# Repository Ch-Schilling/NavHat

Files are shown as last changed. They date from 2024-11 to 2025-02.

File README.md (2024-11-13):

# NavHat
NavHat or Navigaion Hat is a Raspberry Pi HAT made for saling boats. The HAT implements a number of features to make the Raspberry Pi suitable for a sailing boat environment. It provides power to the Raspberry Pi from board supply, collects data from NMEA bus and attached sensors. It provides the hardware base for an Open Source Navigation platform.
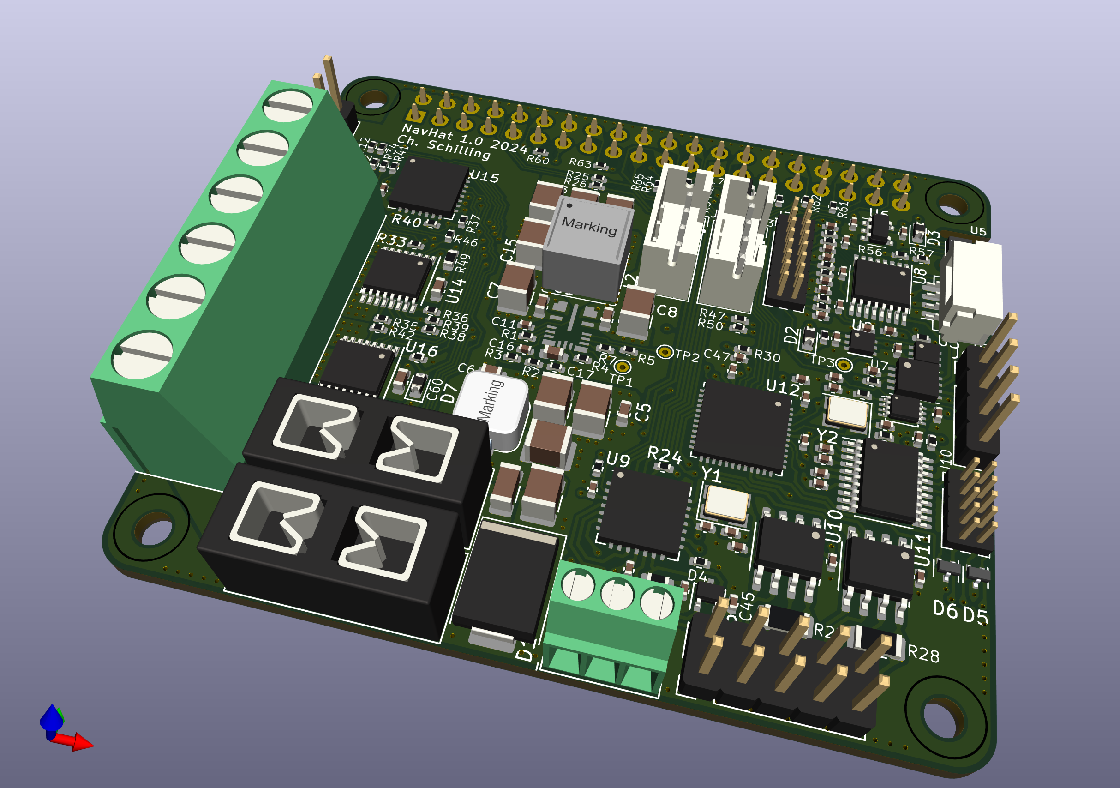
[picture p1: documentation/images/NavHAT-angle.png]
Rendered NavHAT board


**Features:**
* Powered by board supply of 12-28V DC
* Onboard fuses for Raspberry and power outputs
* Four Power Outputs of up to 6A with current and temperature monitoring
* Very low sleep current
* Wake-up by key or RTC
* barometric sensor
* CAN interface for NMEA2000 network
* RS232 and RS422 interfaces for NMEA0183 devices
* Sensor interfaces with STEMMA and Qwiic compatibility
* Designed for compatibility to Raspberry Pi HAT specification

The board is designed using KiCad. 
For more details, see the corresponding [documentation](./documentation/NavHAT.md).

I hope you like the project as much as I do. In case of interest of the board itself, please contact me.

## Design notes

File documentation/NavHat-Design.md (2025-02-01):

## Design
The design is made using KiCad. It is impressive how well that open source system is capable of drawing schematics and designing PCBs! Cudos to the KiCad team. Get the design files from the KiCad folder.
The board is designed for four copper layers to achieve the densitiy needed for the small footprint of the HAT as well as thermal and EMI reasons. For easyer manufacturing, components are populated on the top side only. KiCad and open hardware logos are printed on the bottom side of the board.

### Power Supply
To operate a Raspberry Pi with Navigation HAT independent of other installation, two fuses are on board. F1 (approx. 3A) is installed in the path of the power supply for the Raspberry Pi, F2 (approx. 20A) is in place for the four power outlets.
The fuses are specified for 32V DC, therefore the supply voltage shall not exceed this value.
To achieve high efficiency, low noise, low stand-by current and a wide voltage input the TI LM62460 was chosen. The part also offers a wide range switching frequency and a spread spectrum option. To optimize efficiency, the switching frequency is set to 488kHz. Higher frequencies would allow to use smaller inductors. An EMI filter is used at the battery side. Electrolythic capacitors are waived, purely ceramic capacitors are used. See schematics page 2 and the [datasheet](https://www.ti.com/product/de-de/LM62460) of the manufacturer.
The Enable signal EN_POWER of the device is controlled by a flip-flop U4. EN_POWER is high and remains high if POWER_ON gets low by an external signal like a button, power-on cycle or an interrupt of the RTC. The flip-flop consumes very little power, it has to remain on by a low Iq linear regulator U2. In case of shutting down the Raspberry Pi, the gpio-poweroff driver is used to rise the clock signal of the flip-flop, disabling the DC/DC converter and put it into µA current consumption sleep mode. To do so, this needs to be added in the /boot/firmware/config.txt file:
```
dtoverlay=gpio-poweroff,gpiopin=5,active-delay-ms=1000
```
The active-delay is not mandatory, but seems to be a good idea.
> Note: Make sure that there are no pending interrups of the RTC, otherwise the flip-flop cannot change state and turn off the DC/DC converter.

### Power Outlets
To control lights, relays or board instruments 4 power outlets are available. The high side switche family [TPS2HB](https://www.ti.com/product/TPS2HB16-Q1) of TI is used. The parts provide low R_on resistance, current limiter and -monitoring as well as temperature monitoring. Made for the automotive market, they seem to be a good fit for boating applications, too. The parts are controlled via a I2C port extension device MCP23017. To save the part from reverse polarity 15kOhm resistors are used in all digital paths as described in the application notes.
A fraction of the output current can be fed throug a sense resistor to measure the output current. The voltage across the shunt resistor can be measured by the on-board ADC. Optionally, the first two switches can be controlled by the PWM engine of the Raspberry Pi. Please be aware that not all features of that mini computer can be used at the same time.
> Warning: Do not drive PWM and the corresponding pin of the IO expander at the same time. One of these signals shall remain as an input.

### NMEA Interfaces
The NMEA 2000, CAN interface is implemented using a Microchip MCP25625. The MCP25625 is a more modern and compact device containing a MCP2515 and corresponding bus driver. It creates a one chip solution from SPI to CAN bridge. From the Raspberry Pi's perspecive the MCP2515 driver is used. Make sure the /boot/firmware/config.txt contains the following:
```
dtparam=spi=on
dtoverlay=mcp2515-can0,oscillator=20000000,interrupt=25,spimaxfrequency=2000000
```
In a console, configure the CAN bus for NMEA 2000:
```
sudo ip link set can0 up type can bitrate 250000
sudo ip link set can0 txqueuelen 65536
```
Check for can0 interface using
```
ip link
```
candump displays the traffic in a console. NMEA 2000 bus data should be easily visible but not readable. 
```
candump can0
```

For more details pyssel describes to setup NMEA 2000 with a CAN HAT on their [webpage](https://pysselilivet.blogspot.com/2022/05/waveshare-can-hat-with-signal-k.html)

For NMEA 0183 devices and/or other serial devices, a MAX14830 bridges SPI to quad UART. The first two UARTs are converted into RS-422 signals and fed to connector J9. The last two UARTs can be converted to RS-232 signals and fed to connector J10. One can use the TTL signals but one has to disable the converter chip U13 and put it into shutdown mode. The quad UART U12 could have its own quatz, since it has a wide possibility of options to create its clocks, the clockout of the CAN chip U9 shall be used instead.
The CAN and RS-422 interfaces have an option of a termination resistor of typically 120Ohm, but these resistors are not populated by default. ESD protection diodes are used except for the RS-422 devices, they have large enough built-in protection.

### Sensors and Sensor Interfaces
There are a wide variety of sensors with I2C interface. On board, the following parts share the user accessible I2C bus of the Raspberry Pi:
* MCP23017 I/O Port extension for controlling the power outlets
* ADS1119 analog to digital converter for measuring current and temperature of the power outlets
* MAX31343 RTC for wake up calls
* BMP390 barometric pressure sensor

The BMP390 is susceptible to stress. It is placed at the edge of the board in between two cutouts. Stress to the board is not passed to the part where the sensor is soldered to.
  
There are two [STEMMA](https://learn.adafruit.com/introducing-adafruit-stemma-qt/what-is-stemma) connectors J3 and J4 as well as a STEMMA QT / Qwiic connector J5. The power pin of J5 is hooked up from linear regulator U2. It provides 3.3V even if the main DC/DC converter is switched off. This allows low power sensors to continue to operate without operation of the computer. The header J7 also carries the two I2C signals. There should be plenty of options to add I2C sensors to the system.
Connector J2 is prepared for 1-wire devices inclusive 5kOhm pull-up and 3.3V and 5V to chose from.

A nice option for environmental monitoring of temperature and humidity, the part HDC3020 can be used. It is not on board because the environment of the computer system is typically not representative for the environment to be monitored. The part continues to measure these parameters, even if there is no I2C communication. It stores the minimum and maximum measurements of temperature and rel. humidity. This is an excellent choise to connect to J5 to be powered, even when the Raspberry Pi is off. The computer can read the min. and max. readings when it is awake again.

### Configuration
#### EEPROM
Page 6 of the schematics shows hardware configurations of the board. The HAT specification requires a EEPROM describing the HAT and holds information about power delivery and required drivers. Unlike the proposal of the HAT specification, a software configurable EEPROM is used. This allows to set the I2C address as well as the write protection of the device within a minimal board space. Gaining write access to the device from user space is relatively complicated, therefore an accidential write access is highly unlikely.

Writing to the configuration EEPROM is easy using the software gpio driver. A new bus is createt, for example 9. Use this driver only temporary before accessing the configuration memory to prevent unwanted modification.
```sh
sudo dtoverlay i2c-gpio i2c_gpio_sda=0 i2c_gpio_scl=1 bus=9
```
Check if somebody is home. The memory chips are expected in the address range 0x50 ... 0x57.
```sh
i2cdetect -y 9

     0  1  2  3  4  5  6  7  8  9  a  b  c  d  e  f
00:                         -- -- -- -- -- -- -- -- 
10: -- -- -- -- -- -- -- -- -- -- -- -- -- -- -- -- 
20: -- -- -- -- -- -- -- -- -- -- -- -- -- -- -- -- 
30: -- -- -- -- -- -- -- -- -- -- -- -- -- -- -- -- 
40: -- -- -- -- -- -- -- -- -- -- -- -- -- -- -- -- 
50: 50 -- -- -- -- -- -- -- -- -- -- -- -- -- -- -- 
60: -- -- -- -- -- -- -- -- -- -- -- -- -- -- -- -- 
70: -- -- -- -- -- -- -- --
```

check configuraton directory for files and scripts. The eep tools are used to create binary files from a text description and writing the image into the configuration memory. See HAT documentation for more details. A device tree blob can be added to the binary description which is executed at boot time. The power-5A.dtbo promisses to provide 5A current. The Raspberry Pi 5 is complaining about a weak power supply if that is not provided.
```sh
eepmake  -v1 eeprom_navhat.txt eeprom_navhat.eep power-5A.dtbo
```
The shell script eepflash.sh finally writes the image into the memory device.
```sh
sudo eepflash.sh -w -f eeprom_navhat.eep -d=9 -t=24c64
```
To set the I2C Address of the device or write protecting the memory content, eeprom_config.py can be used. 
```sh
python3 eeprom_config.py -b 9 -a 0x52 --write-protect
```
changes the address to 0x52 and sets the write protection.
The device tree blob is created from its source file like that:
```sh
dtc -@ -O dtb -I dts -o power-5A.dtbo power-5A.dts
```
The build.sh script executes these commands in the correct order.

#### SPI 
Chip select and interrup pin for the CAN- and UART controller are prepared for two options. The options can be chosen by using the corresponding resistor.

#### I2C
The signal I2C_ADDR0 can be set to logic 0 or logic 1. It is connected to the lowest address bit of the pressure sensor U5, the ADC U8 and the port extender U15. The I2C address of these devices can be rised by 1 commonly in case of conflict with other devices.

The following table shows the I2C addresses of the different devices. A0 corresponds to the configuration of the I2C_ADDR0 which can be set by the resistors R56 and R57. A0 = 0 if R57 is populated and A0 = 1 if R56 is populated, respectively.

|Device|Address|
|:-----|:---|
|MCP23017|0x22 + A0|
|BMP390|0x76 + A0|
|ADS1119|0x48 + A0|
|MAX31343|0x68|
|HDC3020|0x44|

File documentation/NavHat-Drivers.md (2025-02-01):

## Drivers

To make full advantage of the board, two drivers need attention: the CAN device MCP25625 and the quad UART MAX14830. These communication devices share one oscillator. The CAN chip needs to be configured to provide a clock output which is used as a clock input for the quad UART device. The quad UART driver is not included in the kernel by default, it must be added as max310x module. 
The clock output did not find attention by the kernel maintainers, so far. A patch is added that allows a user friendly configuration of the clock output signal.

To compile the kernel follow these well [documented steps of the raspberry pi documentation.](https://www.raspberrypi.com/documentation/computers/linux_kernel.html#configure-the-kernel)

To enable the quad UART max14830, make sure the .config shows this driver as a module:
```
CONFIG_SERIAL_MAX310X=m
```
Add the patch for the mcp250x driver and corresponding device tree files or swap the entire kernel source files.
Compile the kernel afterwards.

### CAN driver
To configure the output clock CLKOUT, a field was introduced in the mcp2515-can0-overlay.dts device tree overlay file.
```
          clkout-prescale = <0>;
```

The driver looks for that entry during probing and sets the CANCTRL register accordlingly. A value of 0 does not enable clock output and remains the output low. In this case, the driver behaves no different than the original version does.
Valid parameters for clkout-prescale are 1,2,4 and 8 which divides the input clock by 1 (same frequency), 2 ,4 or 8 respectively.

This information can be found by the driver using device_property interface during probing:
```
	/* check clkout property and convert it to register value */
	if(device_property_present(&spi->dev, "clkout-prescale")) {
		dev_info(&spi->dev, "clkout-prescale: found\n");
		device_property_read_u32(&spi->dev, "clkout-prescale", &clkout_prescale);
		dev_info(&spi->dev, "clkout-prescale found: %d\n", clkout_prescale);
		if(clkout_prescale) {
			if (clkout_prescale > 8)
				return -ERANGE;

			clkout_prescale = (clkout_prescale >> 1);
			clkout_prescale = (clkout_prescale == 4 ? 3 : clkout_prescale) | CANCTRL_CLKEN;
			dev_info(&spi->dev, "(CS) clkout-prescale register value: 0x%02x.", clkout_prescale);
		}
	}
	...
```
This is for illustration only, no actions needed for commissioning.

### UART driver
The driver for the MAX14830 works without modification but a device tree overlay is needed to hook it correctly in the SPI 1 bus. The following line creates a device-tree blop which needs to be copied to /boot/firmware/overlays using root priviledges.
```
dtc -@  -O dtb -I dts -o max14830-spi1.dtbo max14830-spi1-overlay.dts 
```

Describing the clock input is 2.5MHz, 1/8 of the 20MHz oscillator for the CAN device. The UART uses a PLL and internal prescaler to adjust the baudrate as close as pssible to the desired one. Below are exceprts from max14830-spi1-overlay.dts.
```
	fragment@3 {
		target-path = "/clocks";

		__overlay__ {
			max14830_xtal: max14830_xtal {
				compatible = "fixed-clock";
				#clock-cells = <0>;
				clock-frequency = <2500000>;
			};
		};

	};
```
Also, clock-names has to be "osc" for an external input. "xtal" is used for a quarz.
```
	fragment@1 {
		target = <&spi1>;

		__overlay__ {
			#address-cells = <1>;
			#size-cells = <0>;

			pinctrl-names = "default";
			pinctrl-0 = <&spi1_pins &spi1_cs_pins>;

			cs-gpios = <&gpio 17 1>;  //GPIO_ACTIVE_LOW>;
			status = "okay";

			max14830: max14830@0 {
				compatible = "maxim,max14830";
				reg = <0>;

				#address-cells = <1>;
				#size-cells = <0>;
				gpio-controller;
				#gpio-cells = <2>;

				spi-max-frequency = <5000000>;
				interrupts = <12 8>; // 2:IRQ_TYPE_EDGE_FALLING>;  8:low
				interrupt-parent = <&gpio>;

				pinctrl-0 = <&int_pins>;
				pinctrl-names = "default";

				clocks = <&max14830_xtal>;
				clock-names = "osc";
			};
		};
	};

```
It seemed that some interupts got lost when the interrupt signal was configured as falling edge. Setting it to low (8) seems to solve that problem.

To load these drivers at boot time, make sure they are mentioned in the /boot/firmware/config.txt file:
```
...
dtparam=spi=on
dtoverlay=mcp2515-can0,oscillator=20000000,interrupt=25,spimaxfrequency=2000000,clkoutprescale=8
dtoverlay=max14830-spi1
...
```

If configured correctly the two drivers appear in dmsg after reboot.
```
...
[   11.391625] mcp251x spi0.0: clkout-prescale: 4
[   11.417303] mcp251x spi0.0 can0: MCP2515 successfully initialized.
...
[   11.471622] spi1.0: ttyMAX0 at I/O 0x0 (irq = 172, base_baud = 3750000) is a MAX14830
[   11.479118] spi1.0: ttyMAX1 at I/O 0x1 (irq = 172, base_baud = 3750000) is a MAX14830
[   11.483086] spi1.0: ttyMAX2 at I/O 0x2 (irq = 172, base_baud = 3750000) is a MAX14830
[   11.483433] spi1.0: ttyMAX3 at I/O 0x3 (irq = 172, base_baud = 3750000) is a MAX14830
...
```

The CAN driver mcp251x displays the clkout-prescale if found and its successful initialization. The single nodes of the UART can be accessed using /dev/ttyMAX0 ... /dev/ttyMAX3. Make sure to turn off hardware handshaking, because these lines are not wired. The upper two (ttyMAX2 and ttyMAX3) can be configured to use the RS-232 level shifter or to keep the TTL signals. Enable and shutdown of the the level shifter are controlled by GPIO0 and GPIO1 of the UART. Since the UART device acts as a standard gpio controller these lines can be set as follows:
```
gpioset --drive=push-pull gpiochip14 0=1 1=0
```
Sets GPIO0 to high and GPIO1 to low, which disables the level shifter.

```
gpioset --drive=push-pull gpiochip14 0=0 1=1
```
Sets GPIO0 to high and GPIO1 to low, which enables the level shifter.

Depending on the configuration, gpiochip14 might not be the correct device. Try to use gpiodetect to find the correct one.
```
user@raspberrypi:~ $ gpiodetect
gpiochip0 [pinctrl-rp1] (54 lines)
gpiochip10 [gpio-brcmstb@107d508500] (32 lines)
gpiochip11 [gpio-brcmstb@107d508520] (4 lines)
gpiochip12 [gpio-brcmstb@107d517c00] (17 lines)
gpiochip13 [gpio-brcmstb@107d517c20] (6 lines)
gpiochip14 [MAX14830] (16 lines)
gpiochip0 [pinctrl-rp1] (54 lines)
```
gpioinfo shows the status of all GPIO signals of the system:
```
...
gpiochip14 - 16 lines:
        line   0:      unnamed       unused  output  active-high 
        line   1:      unnamed       unused  output  active-high 
        line   2:      unnamed       unused   input  active-high 
        line   3:      unnamed       unused   input  active-high 
...
```

To see how much data was transferred by the four UARTs as well as the line stati, check the driver information:
```
user@raspberrypi:~ $ sudo cat /proc/tty/driver/max310x
serinfo:1.0 driver revision:
0: uart:MAX14830 port:00000000 irq:172 tx:0 rx:0 DSR|CD
1: uart:MAX14830 port:00000001 irq:172 tx:0 rx:0 DSR|CD
2: uart:MAX14830 port:00000002 irq:172 tx:0 rx:0 DSR|CD
3: uart:MAX14830 port:00000003 irq:172 tx:0 rx:0 DSR|CD
```

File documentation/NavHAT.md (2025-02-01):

# Navigation HAT
The Navigation HAT is a board that connects on top of the Raspberry Pi computer by its 40 pin header. HAT stands for Hardware-Attached-on-Top, the specification can be found [here](https://datasheets.raspberrypi.com/hat/hat-plus-specification.pdf).

Rendered NavHAT board

## Purpose
Navigation HAT is made to help embed the Raspberry Pi in a sailing boat. Of course, it can be used in many other use cases where the hardware features make sense.
On a sailing boat, one is consious about power consumption. Navigation HAT uses a wide input range, high efficiency and low noise step-down switcher providing power to the Raspberry Pi. In operation, powered from the battery of the boat, its efficiency is approx. 95%.
In standby, it uses only a few µA. It can be woken up by a key or by the on-board real time clock (RTC).
Most boats use NMEA 2000 for information exchange between instruments, plotter, autopilot etc. The bus is based on CAN, therefore an important interface is the CAN bus. Older boats might use NMEA 0183, which is based on RS-422. Two UARTs each in RS-422 and RS-232 configuration are populated as well.
To control other loads on the boat, there are four power outputs with current limitation and monitoring as well as other protective features. Barometric readings are essential for wheather observation. A high sensitivity barometric sensor is included. Several connectors are ready for attaching other sensors using a two-wire bus.

## [Installation](./NavHat-Installation.md)

## [Design](./NavHat-Design.md)

## [Drivers](./NavHat-Drivers.md)

## Revision history
### Board Revision 1.0
This board revision is first built in April 2024. It is basically functioning. See CoC of the manufacturer in the documentation folder.

### Known issues
* ~~The quad UART is not commissioned, yet.~~
* ~~One-wire is not commissioned, yet.~~
* The quartz Y1 for the CAN device is a 20MHz version. Schematics needs to be fixed (shows 16MHz version)
* The Raspberry Pi 5 leaves its power-off pin in an undefinded state, too long. The signal oscillates and therefore power-off is not reliable. Use a 1KOhm resistor instead of a 100kOhm for R10. Raspberry Pi 4 is fine with the 100kOhm.
* The pull-up and -down resistors of the RS-232 level shifter for /EN and /Shutdown should be the other way around. A TTL serial link could compete with the outputs of the level shifter before setting them correctly.

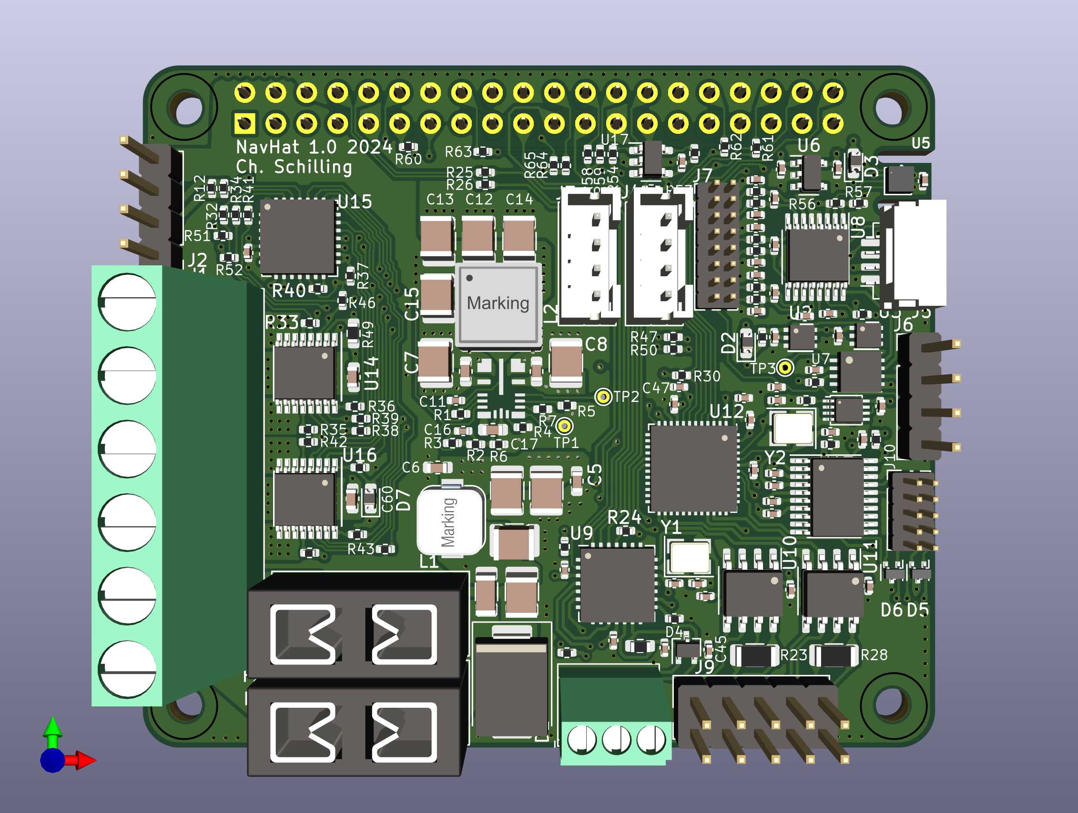
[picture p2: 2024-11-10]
documentation/images/NavHAT-Top.png

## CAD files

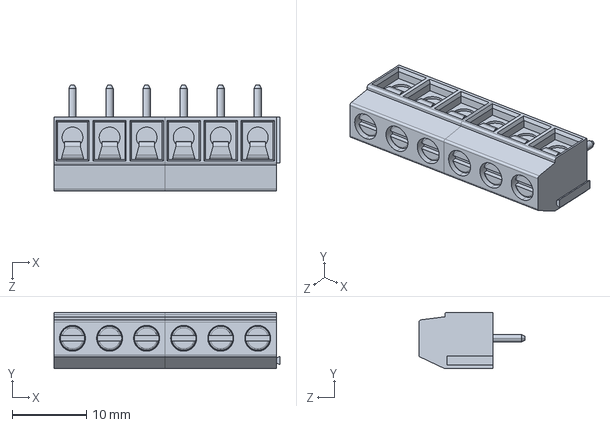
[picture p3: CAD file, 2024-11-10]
KiCad/3D-Step/CUI_DEVICES_TB002-500-06BE.step
30.5 x 7.60 x 14.4 mm
TB002-500-03P_Blue - S x 2

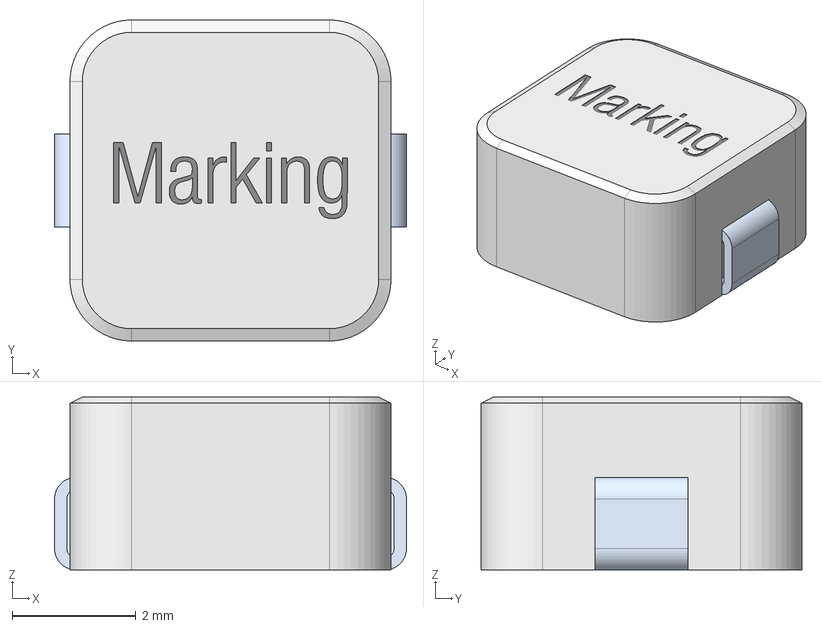
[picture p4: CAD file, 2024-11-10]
KiCad/3D-Step/WE-LHMI_5030.stp
5.70 x 5.20 x 2.80 mm
base
pin

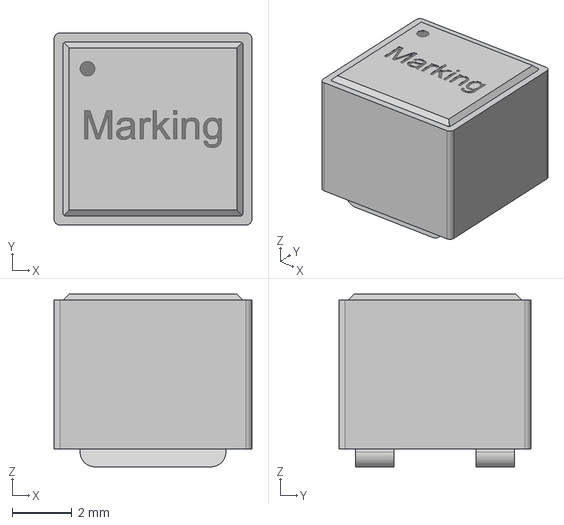
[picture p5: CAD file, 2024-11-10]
KiCad/3D-Step/WE-XHMI-6060.stp
6.65 x 6.45 x 5.80 mm

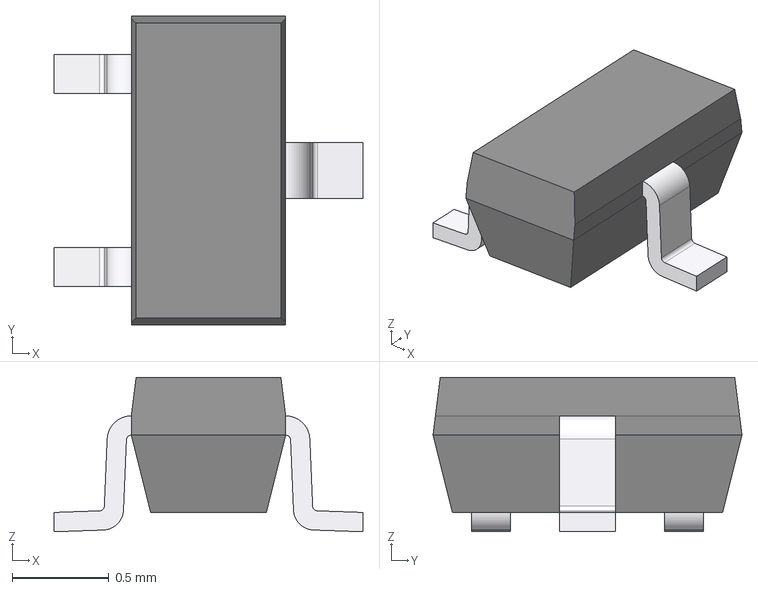
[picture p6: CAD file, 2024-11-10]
KiCad/3D-Step/SOT-523.step
1.60 x 1.60 x 0.8 mm

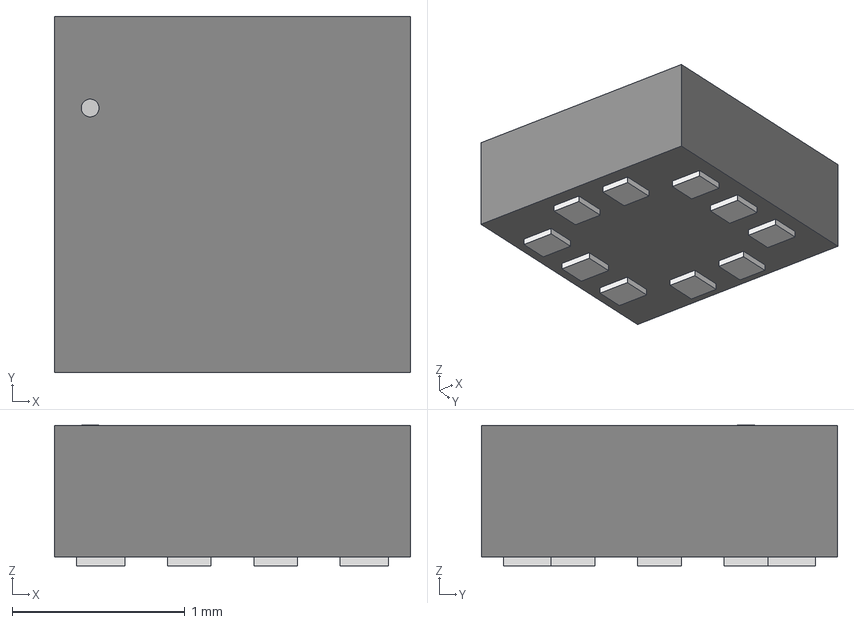
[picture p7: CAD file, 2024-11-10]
KiCad/3D-Step/QFN_BMP388_BOS.step
2.06 x 2.06 x 0.815 mm

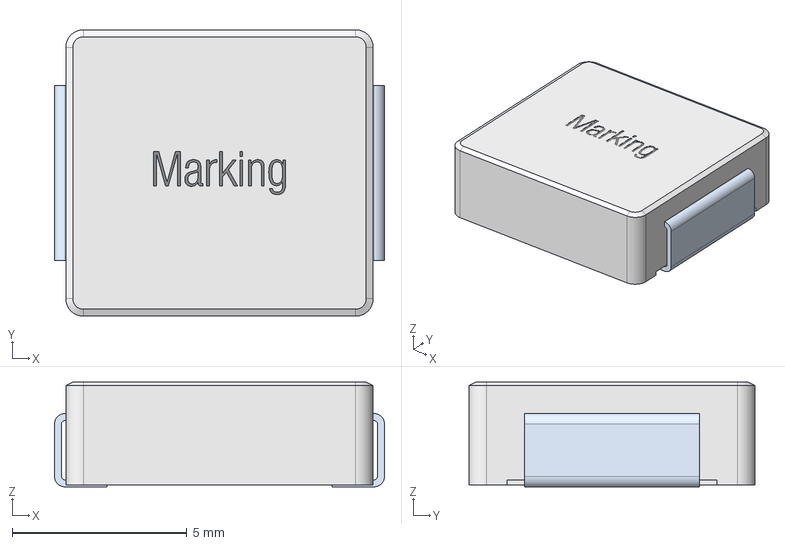
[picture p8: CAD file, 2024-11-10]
KiCad/3D-Step/WE-LHMI-8030.stp
9.45 x 8.20 x 3.00 mm
base
pin

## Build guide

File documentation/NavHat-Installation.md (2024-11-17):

# Installation and Interface Description
Before powering the system, make sure the two fuses are installed. F1 is at the board edge and protects the power path to the Raspberry Pi. Populate with 3A typically. For example, use Littlefuse 0297003.wxnv. F2 is in the path to the power outlets. Let's assume to limit the sum of the current outlets to 20A. Therefore, one can use the Littlefuse 0297020.wxnv, as an example.

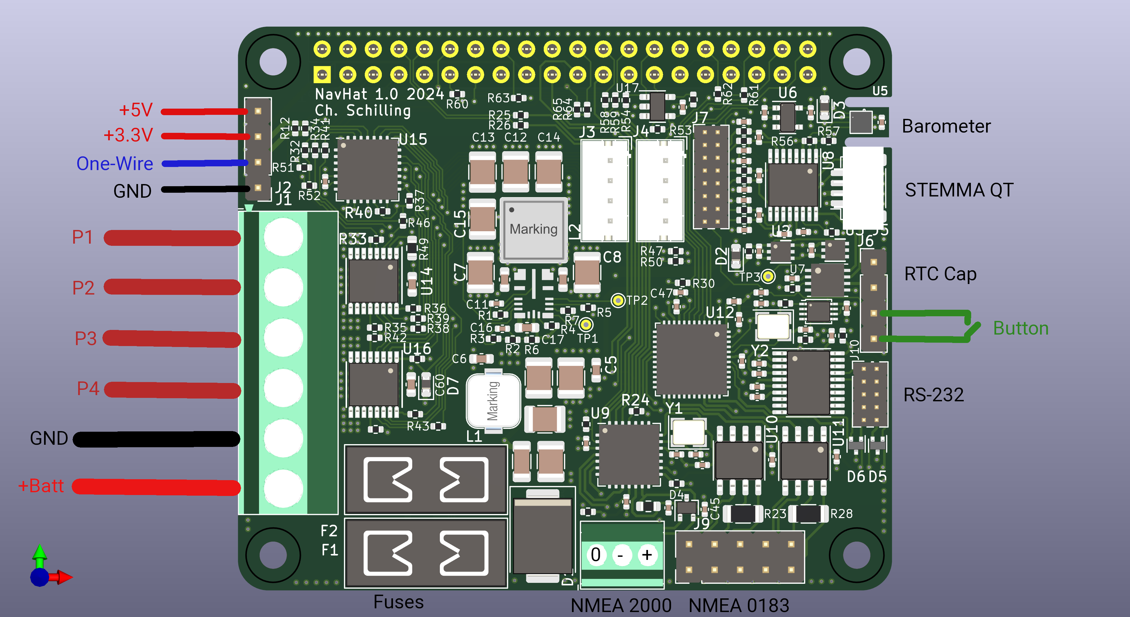
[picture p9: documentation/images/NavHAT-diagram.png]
Diagram and Connections


### Powering the system
J1 is the large screw terminal providing power to the system and connecting loads conrolled by the high-side switches. Positive voltage from the battery is connected closest to the fuses.

|Pin|Connection|
|:--|:---|
|1|P1 Output|
|2|P2 Output|
|3|P3 Output|
|4|P4 Output|
|5|GND, Battery -|
|6|Supply, Battery +|

The screw terminals take wire sizes up to 2.5mm<sup>2</sup>.
> Warning! 
> Use either the USB Power of the Raspberry Pi or the supply for the Navigation HAT board. Do not use both at the same time!

### NMEA 2000 interface
J8 is the small screw terminal for the NMEA 2000 or CAN bus interface. Pin 1 is closest to the fuses.

|Pin|Connection|Color|
|:--|:----|:---|
|1  |GND  |metallic|
|2  |CAN -|blue |
|3  |CAN +|white |

The colors refer to the NMEA cable specification. Use the metallic shield for ground connection.

### Power-on and RTC backup
J6 is reserved for RTC battery or super capacitor as well as the power-on button to switch the flip-flop and therefore start the DC/DC switcher.

|Pin|Connection|
|:--|:---|
|1|GND |
|2|VBATT_RTC |
|3|POWER_ON  |
|4|GND |

Connect POWER_ON to GND for an instant to turn on the system. This is a good application for a power button. 
> Note: It is planned to use the button during operation as a signal and long-press to initiate shut-down. This is not implemented, yet.

### One-Wire
J2 offers a One-Wire interface. The Bit-banging driver of the Raspberry Pi is used. There is a 5kOhm pull-up resistor on board for a seamless start.

|Pin|Connection|
|:--|:---|
|1|GND |
|2|One-Wire |
|3|+3.3V |
|4|+5V |

The +5V is directly connected to the output of the DC/DC converter. +3.3V is made by the Raspberry Pi and is taken from the 40Pin header. Pin 1 is at the Label J2 or closest to J1.

### Auxilary header J7
J7 offers differential signals to the ADC inclusive external differential reference voltage. Four GPIOs from the Port extender, I2C and a linear 3.3V supply are fed to that header as well.

|Signal |Pin|Pin|Signal |
|:---|:-:|:-:|:---|
| GND | 1 | 2 | LIN3V3 |
| SCL | 3 | 4 | SDA |
| GPIO_A4  | 5 | 6 | AIN3 |
| GPIO_A3  | 7 | 8 | AIN2 |
| GPIO_A2  | 9 | 10| REF_N |
| GPIO_A1  | 11| 12| REF_P |
| GND | 13| 14| CurSenseRef |
| POWER_ON | 15| 16| CurSense |

The current sense signals are hooked up to that header, too. Removing R47 and R50 looses current sense of the power outputs in favour of additional external analogue voltages. See schematics for applied filters to the ADC.

### STEMMA connectors J3 and J4
Two STEMMA connectors for external I2C devices are available. For reference, these signals are hooked up like the table below:

|Pin|Signal|
|:--|:-----|
|1 |SCL |
|2 |SDA |
|3 |LIN3V3 |
|4 |GND |

Pin 3, LIN3V3 is powered from a linear regulator, not from the 3.3V of the Raspberry Pi.

### STEMMA QT / Qwiic connector J5

The miniature version of STEMMA can be used on J5. For reference, these signals are hooked up like the table below:

|Pin|Signal|
|:--|:-----|
|1 |GND |
|2 |+3.3VA |
|3 |SDA |
|4 |SCL |

> Note: +3.3VA is powered from a linear regulator and is active, even when the DC/DC converter is disabled.

### NMEA 0183 / serial connectors
J9 and J10 are connectors for RS-232 and RS-422. Details will be updated later.

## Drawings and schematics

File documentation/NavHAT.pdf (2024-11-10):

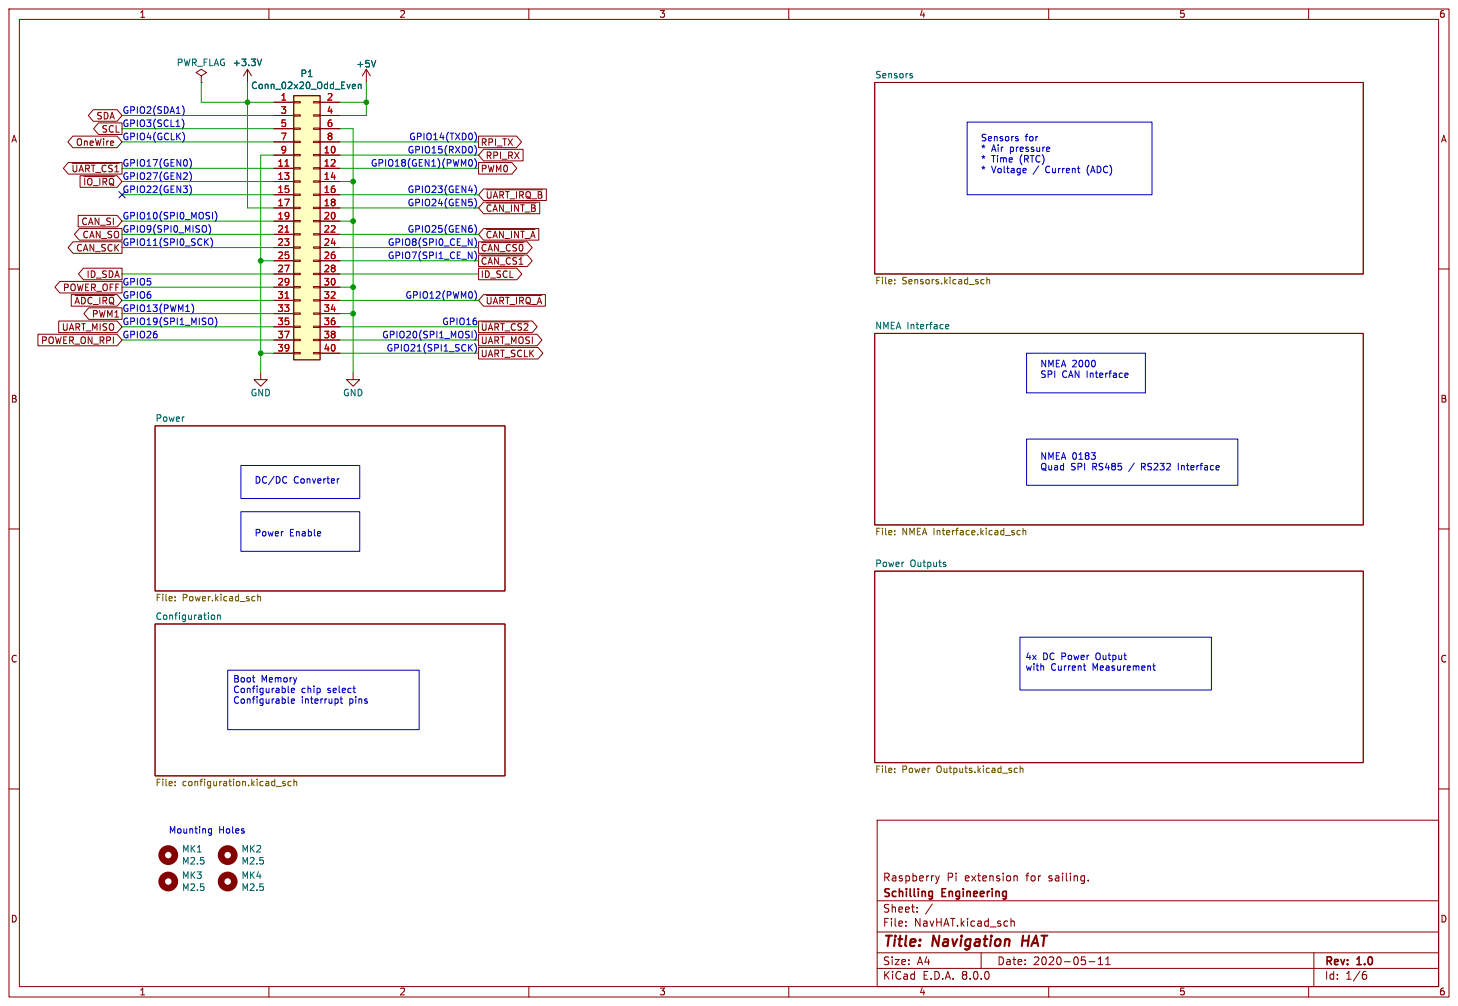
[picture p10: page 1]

Sensors File: Sensors.kicad_sch NMEA Interface File: NMEA Interface.kicad_sch

* Time (RTC) * Voltage / Current (ADC) 4x DC Power Output with Current Measurement Boot Memory

Id: 1/6 Title: Navigation HAT

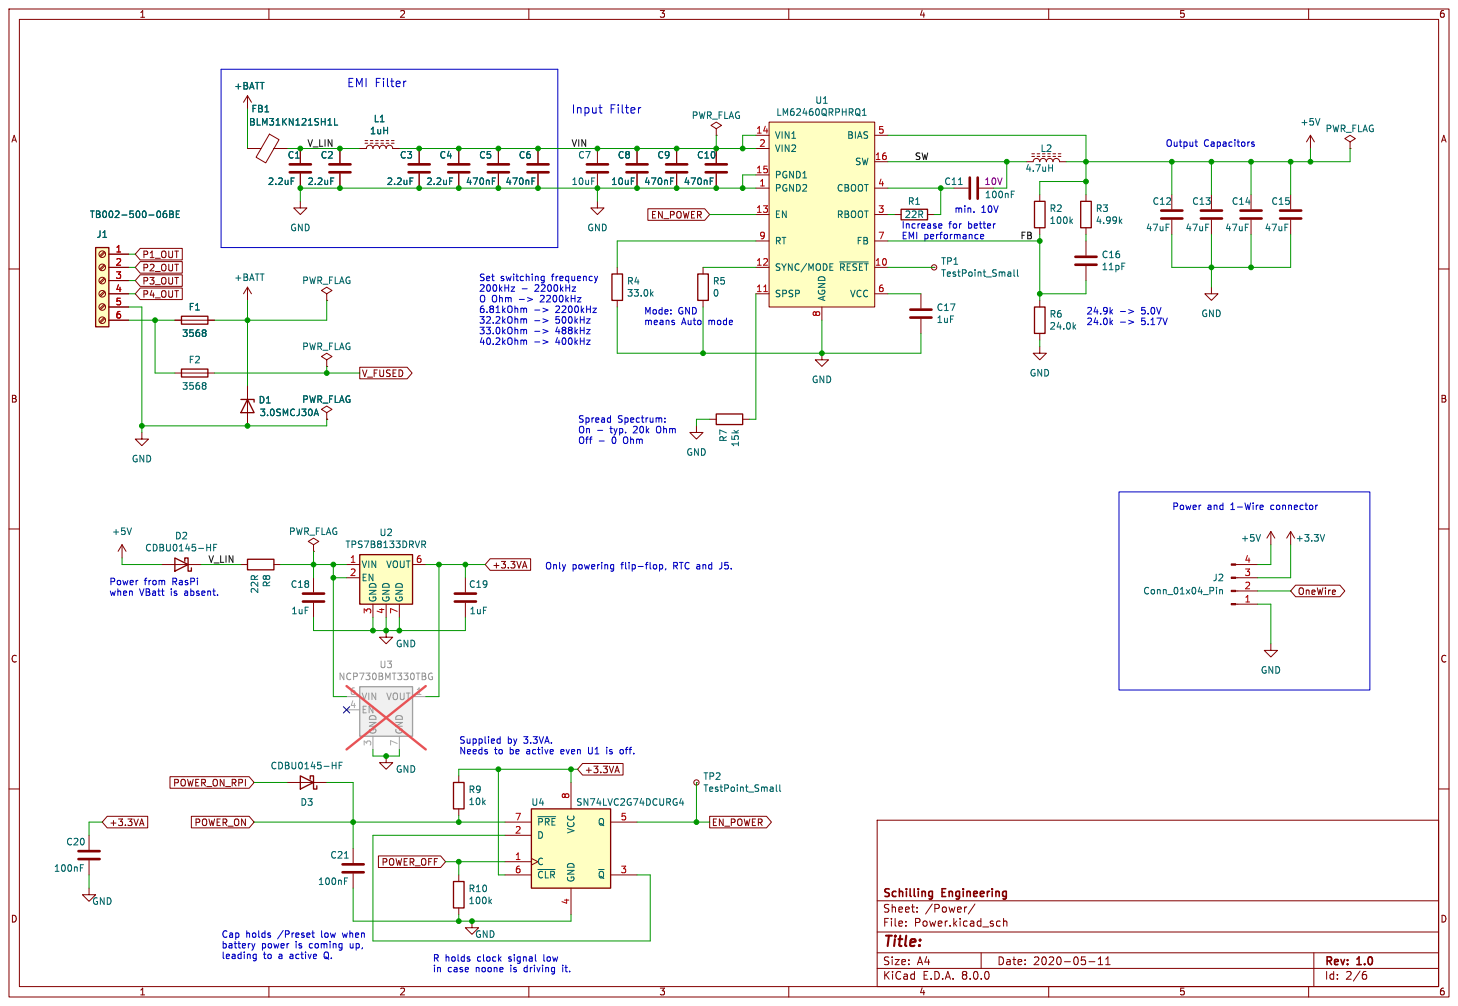
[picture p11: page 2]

EMI Filter
Supplied by 3.3VA. Needs to be active even U1 is off. Mode: GND means Auto mode C9

Increase for better EMI performance

Spread Spectrum: On - typ. 20k Ohm

battery power is coming up,
leading to a active Q.

in case noone is driving it.

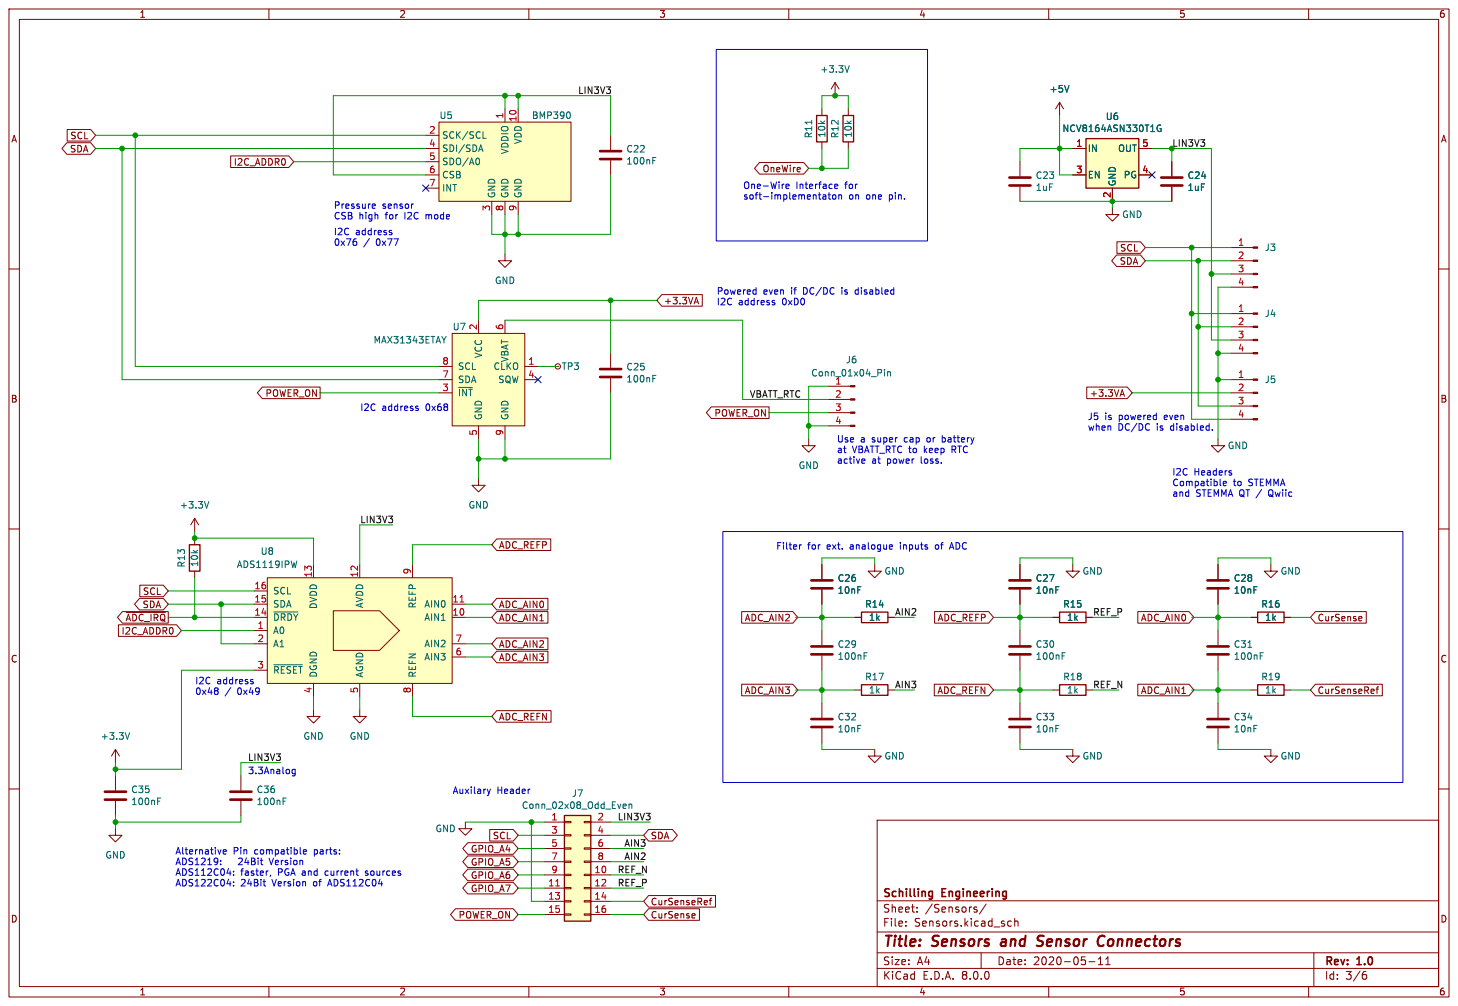
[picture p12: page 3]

1 VDD 10 SCK/SCL 2 GND

3 SDI/SDA 4 SDO/A0 5 CSB 6

and STEMMA QT / Qwiic Pressure sensor CSB high for I2C mode

Powered even if DC/DC is disabled

J5 is powered even when DC/DC is disabled.

active at power loss. 3.3Analog

Id: 3/6 Title: Sensors and Sensor Connectors

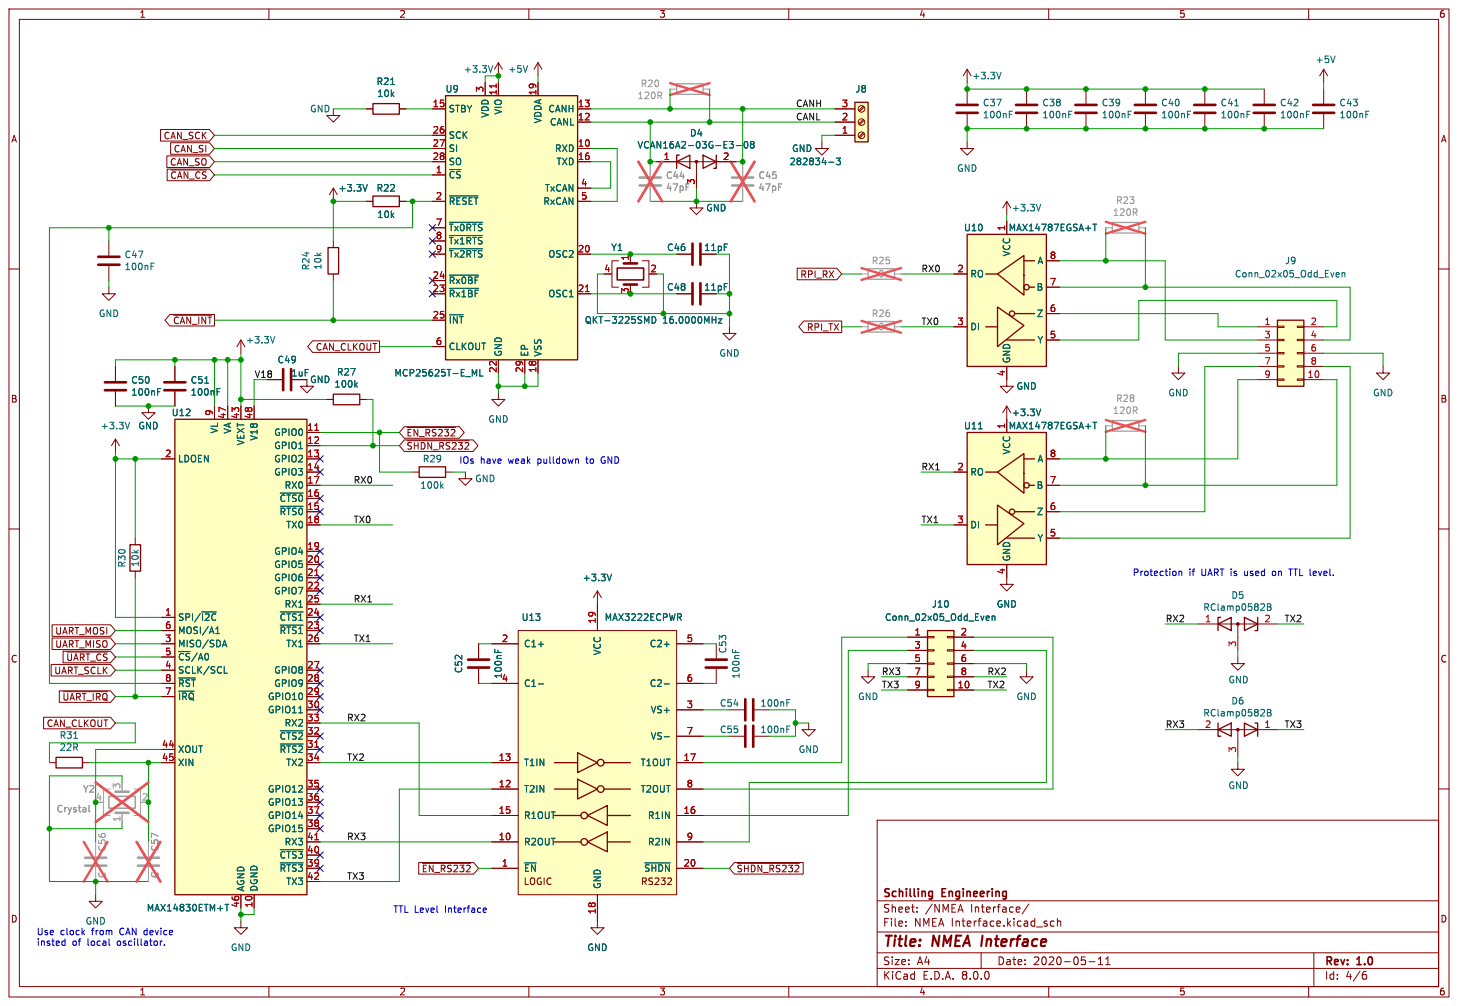
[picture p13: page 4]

Id: 4/6 Title: NMEA Interface

insted of local oscillator.

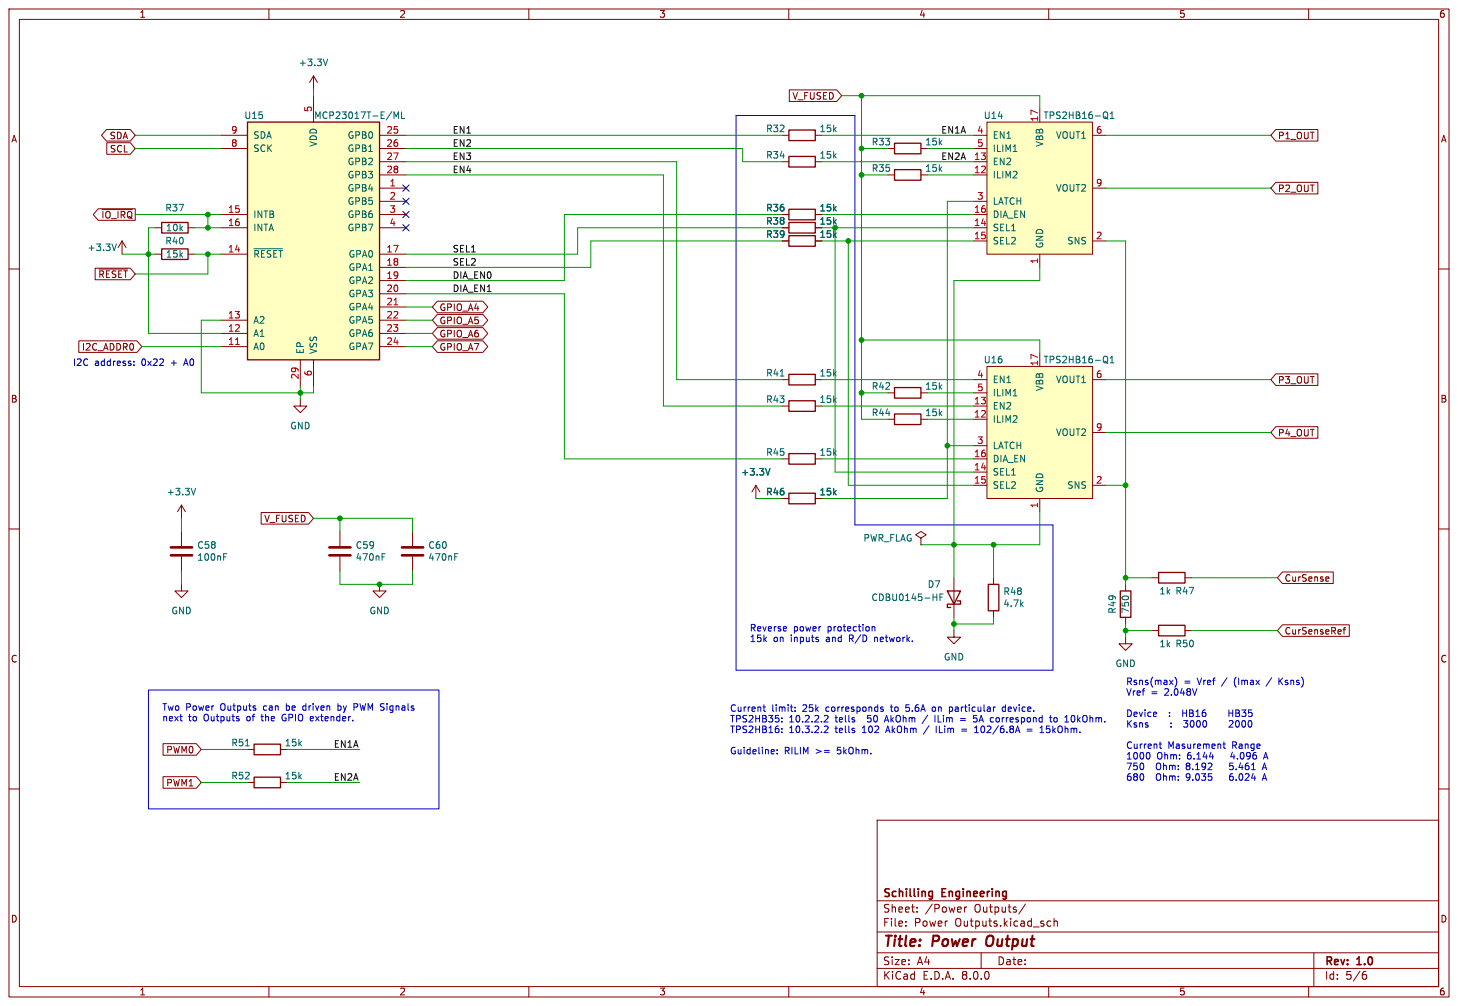
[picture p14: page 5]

Two Power Outputs can be driven by PWM Signals next to Outputs of the GPIO extender.

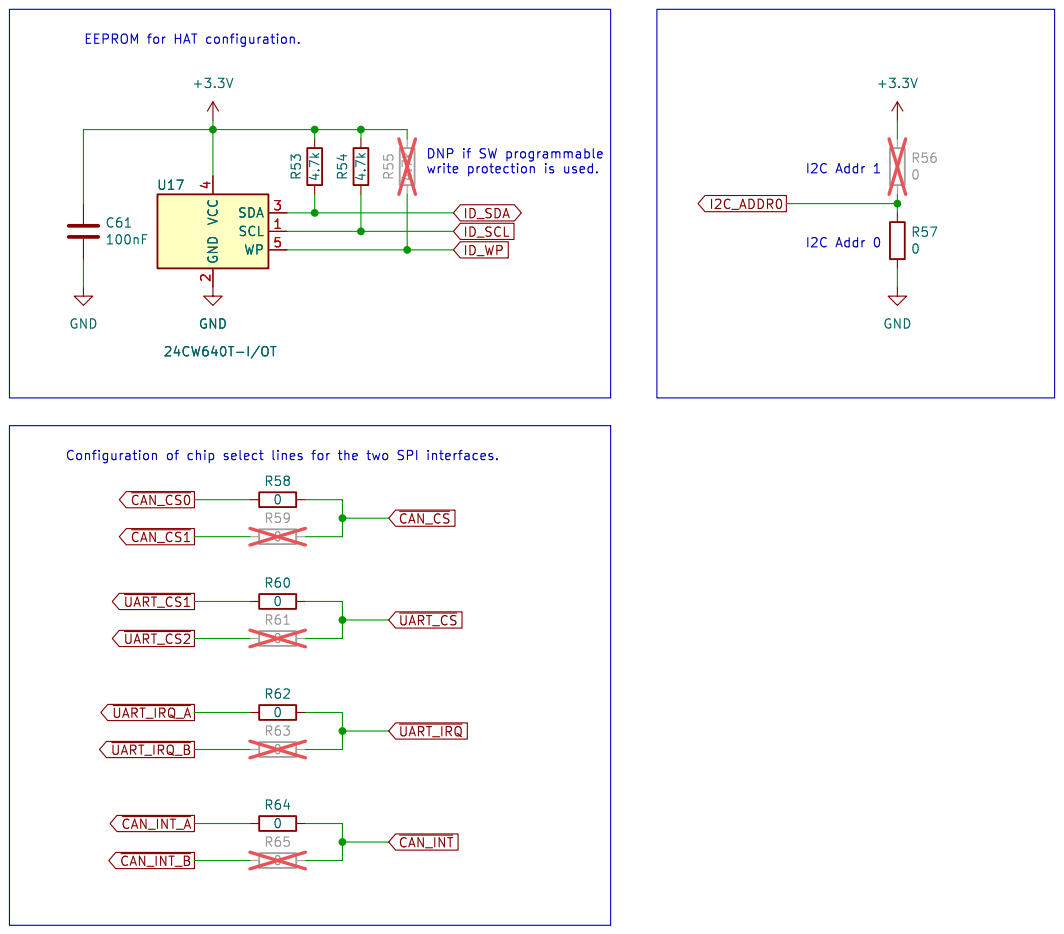
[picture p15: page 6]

File: configuration.kicad_sch Sheet: /Configuration/
Id: 6/6 Title: HAT Configuration

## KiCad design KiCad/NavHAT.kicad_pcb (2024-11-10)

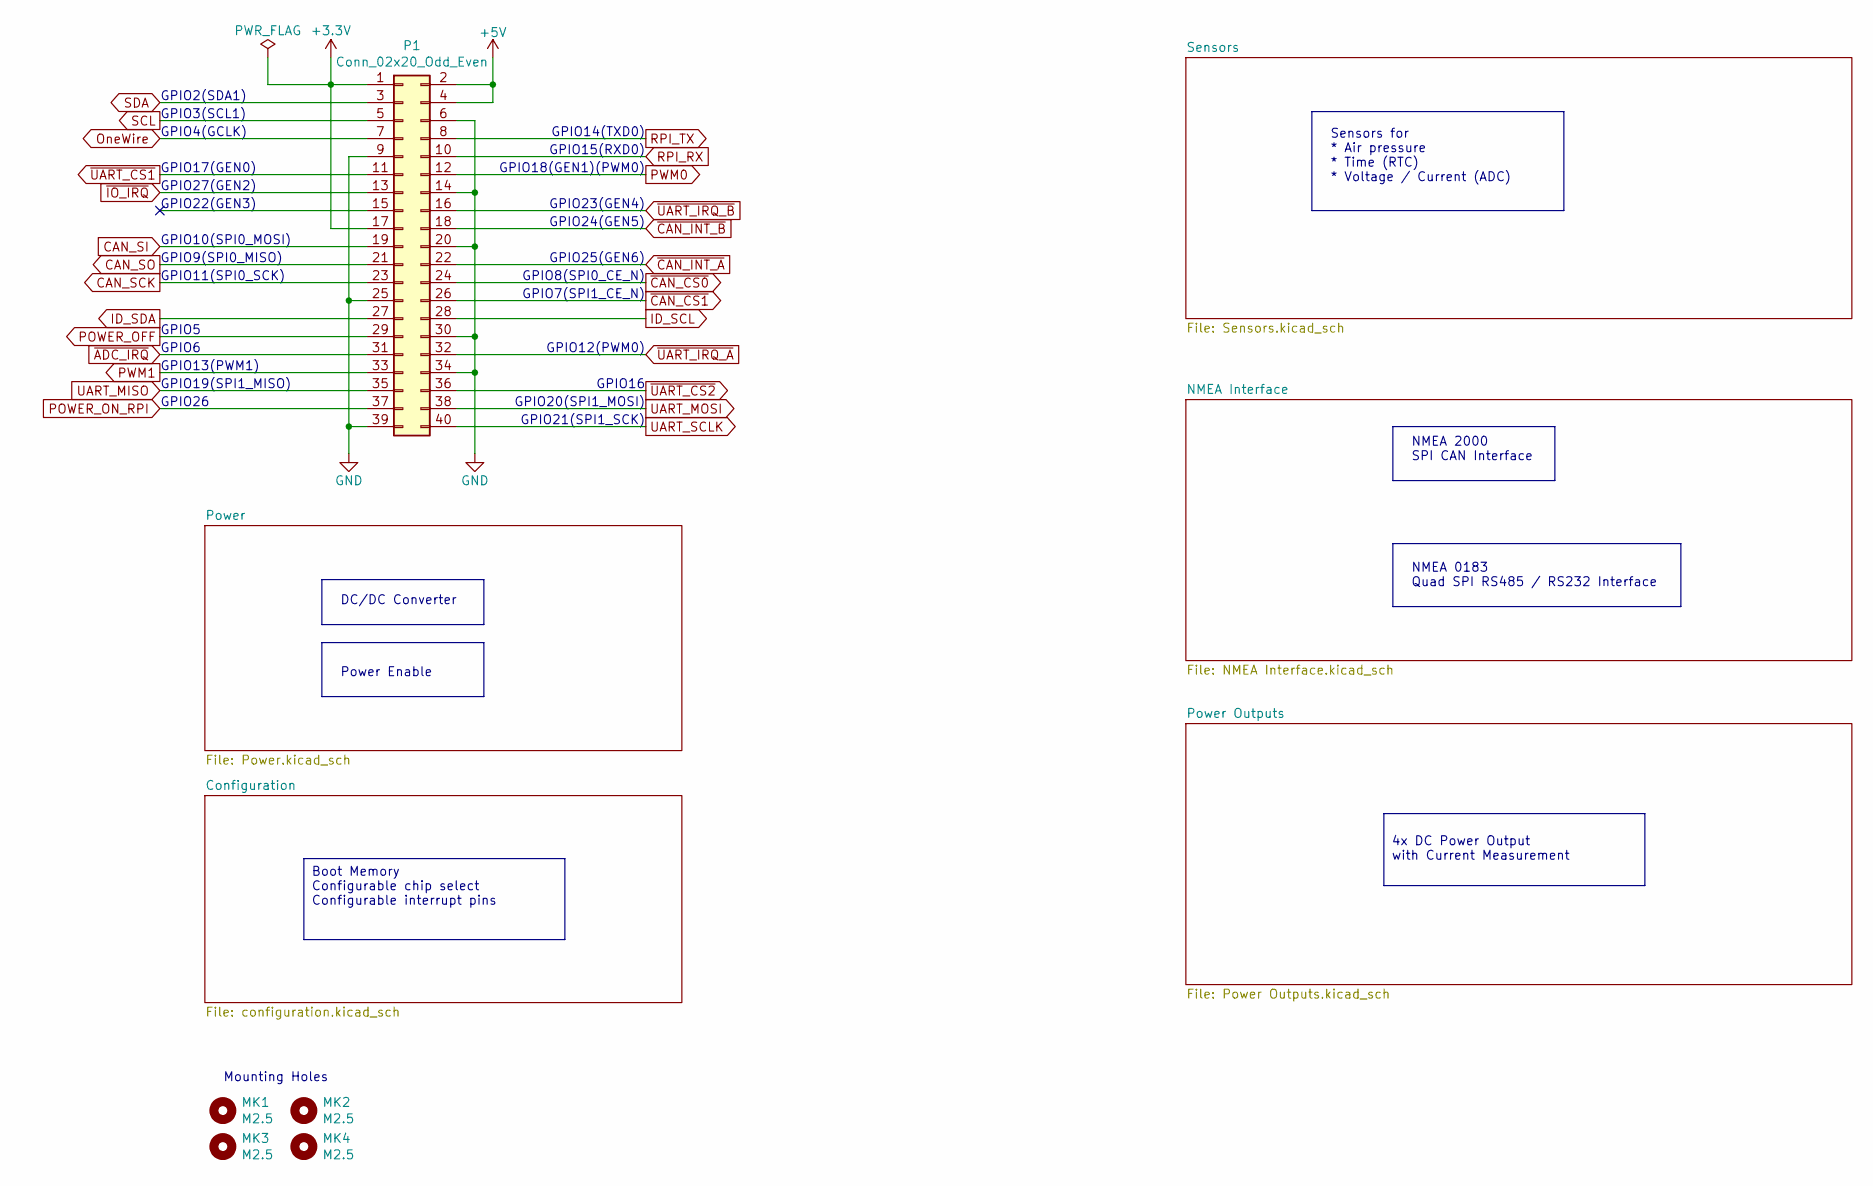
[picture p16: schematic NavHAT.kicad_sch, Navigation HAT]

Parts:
MK1, MK2, MK3, MK4: M2.5; MountingHole_2.7mm_M2.5
P1: Conn_02x20_Odd_Even; PinSocket_2x20_P2.54mm_Vertical

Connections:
+3.3V: P1.1, P1.17; also elsewhere on the board
+5V: P1.2, P1.4; also elsewhere on the board
CAN_SCK: P1.23; also elsewhere on the board
CAN_SI: P1.19; also elsewhere on the board
CAN_SO: P1.21; also elsewhere on the board
GND: P1.6, P1.9, P1.14, P1.20, P1.25, P1.30, P1.34, P1.39; also elsewhere on the board
ID_SCL: P1.28; also elsewhere on the board
ID_SDA: P1.27; also elsewhere on the board
OneWire: P1.7; also elsewhere on the board
POWER_OFF: P1.29; also elsewhere on the board
POWER_ON_RPI: P1.37; also elsewhere on the board
PWM0: P1.12; also elsewhere on the board
PWM1: P1.33; also elsewhere on the board
RPI_RX: P1.10; also elsewhere on the board
RPI_TX: P1.8; also elsewhere on the board
SCL: P1.5; also elsewhere on the board
SDA: P1.3; also elsewhere on the board
UART_MISO: P1.35; also elsewhere on the board
UART_MOSI: P1.38; also elsewhere on the board
UART_SCLK: P1.40; also elsewhere on the board
~ADC_IRQ: P1.31; also elsewhere on the board
~CAN_CS0: P1.24; also elsewhere on the board
~CAN_CS1: P1.26; also elsewhere on the board
~CAN_INT_A: P1.22; also elsewhere on the board
~CAN_INT_B: P1.18; also elsewhere on the board
~IO_IRQ: P1.13; also elsewhere on the board
~UART_CS1: P1.11; also elsewhere on the board
~UART_CS2: P1.36; also elsewhere on the board
~UART_IRQ_A: P1.32; also elsewhere on the board
~UART_IRQ_B: P1.16; also elsewhere on the board

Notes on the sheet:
Boot Memory Configurable chip select Configurable interrupt pins
4x DC Power Output with Current Measurement
NMEA 2000 SPI CAN Interface
GPIO26
GPIO8(SPI0_CE_N)
GPIO18(GEN1)(PWM0)
GPIO14(TXD0)
GPIO2(SDA1)
GPIO22(GEN3)
GPIO10(SPI0_MOSI)
GPIO16
GPIO6
Power Enable
GPIO5
GPIO23(GEN4)
GPIO3(SCL1)
GPIO9(SPI0_MISO)
Mounting Holes
GPIO24(GEN5)
GPIO11(SPI0_SCK)
GPIO13(PWM1)
GPIO21(SPI1_SCK)
GPIO20(SPI1_MOSI)
NMEA 0183 Quad SPI RS485 / RS232 Interface
GPIO17(GEN0)
GPIO7(SPI1_CE_N)
GPIO4(GCLK)
GPIO19(SPI1_MISO)
GPIO12(PWM0)
Sensors for * Air pressure * Time (RTC) * Voltage / Current (ADC)
GPIO25(GEN6)
GPIO27(GEN2)
GPIO15(RXD0)
DC/DC Converter

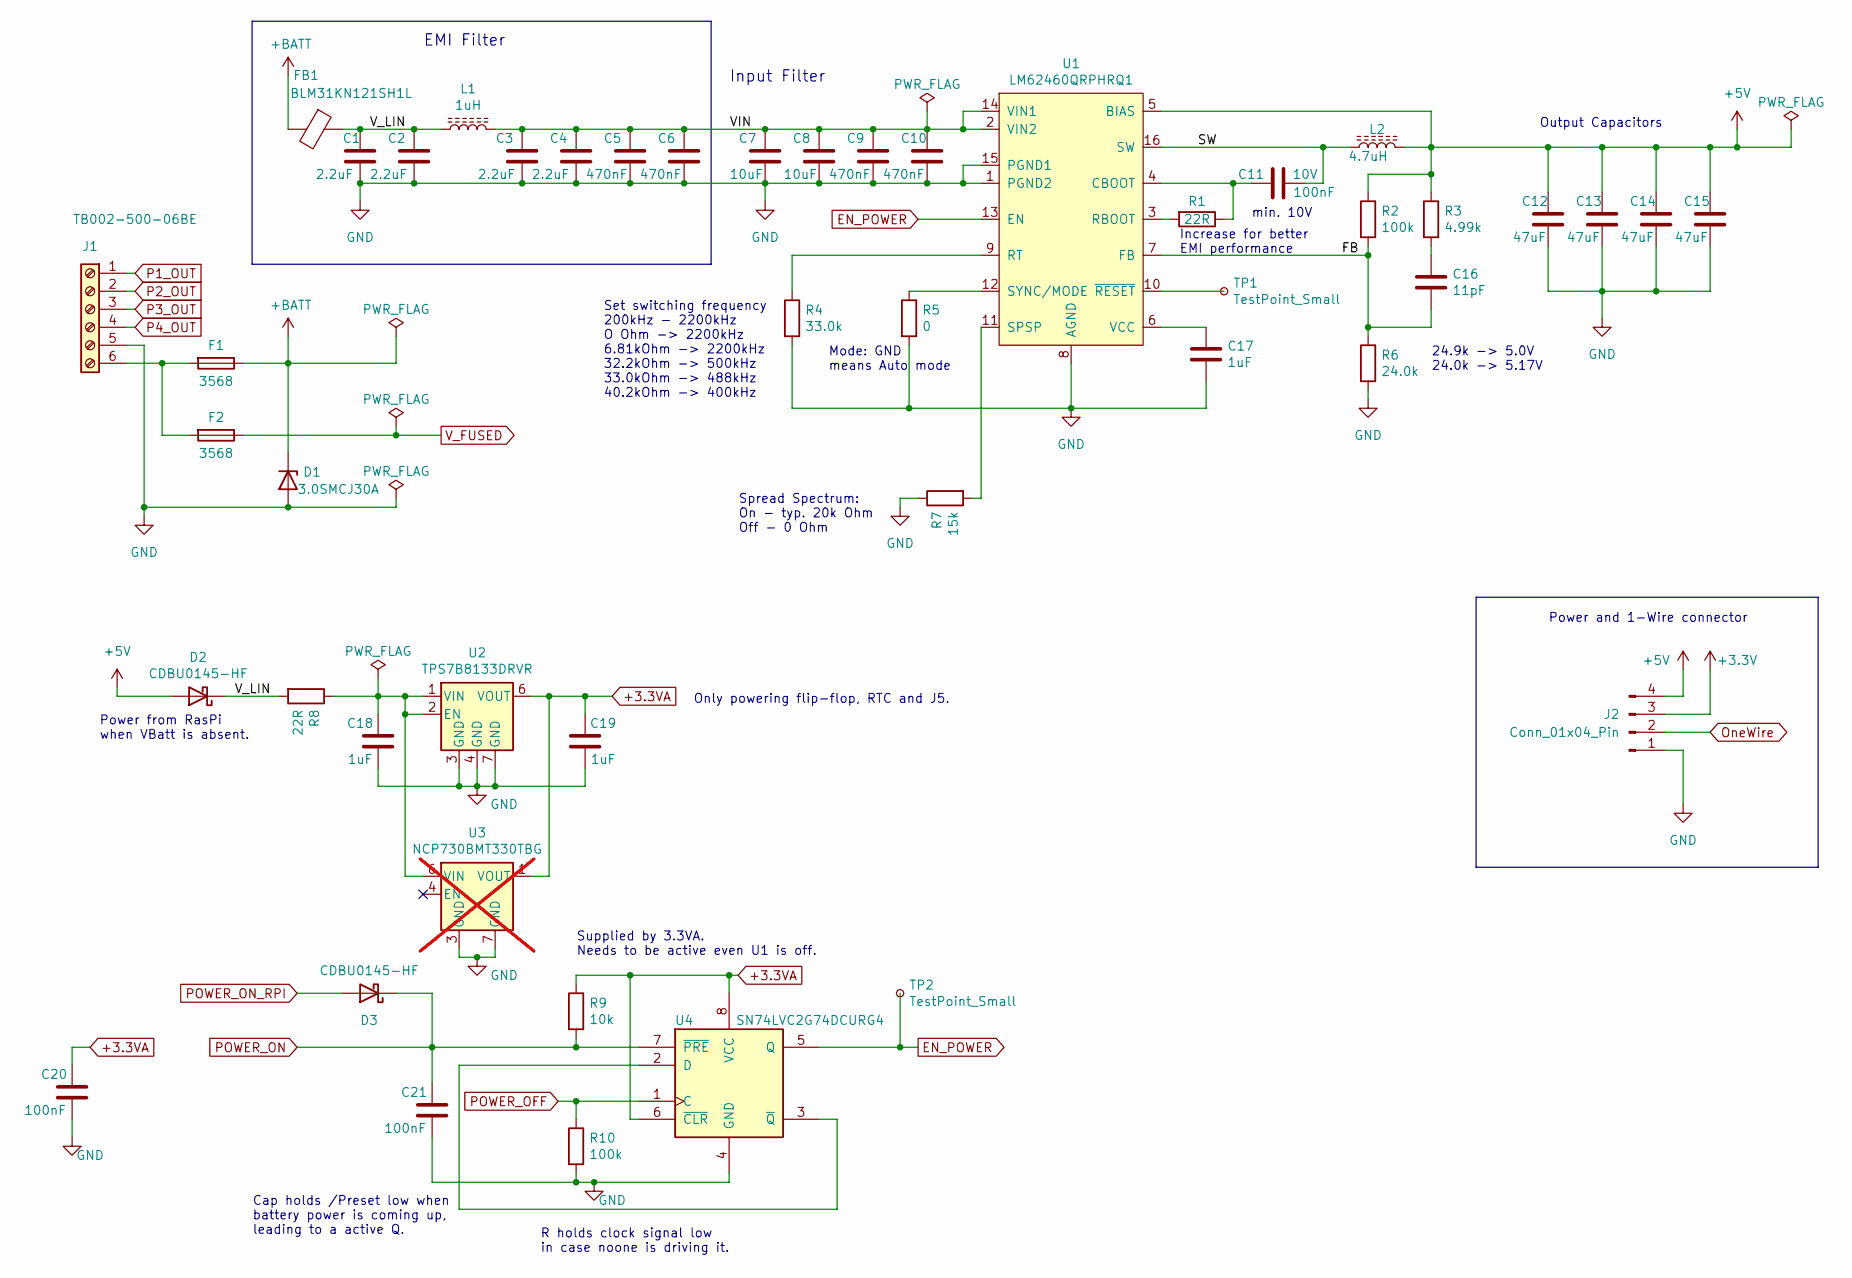
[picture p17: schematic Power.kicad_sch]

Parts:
C1, C2, C3, C4: 2.2uF; C_1210_3225Metric; Voltage Rating 50V
C5, C6, C9, C10: 470nF; C_0603_1608Metric; Voltage Rating 50V
C7, C8: 10uF; C_1210_3225Metric; Voltage Rating 50V
C11: 100nF; C_0402_1005Metric; Voltage Rating 10V
C12, C13, C14, C15: 47uF; C_1210_3225Metric; Voltage Rating 10V
C16: 11pF; C_0402_1005Metric
C17: 1uF; C_0603_1608Metric
C18: 1uF; C_0402_1005Metric; Voltage Rating 50V
C19: 1uF; C_0402_1005Metric
C20, C21: 100nF; C_0402_1005Metric
D1: 3.0SMCJ30A; D_SMC; Voltage Rating 30V
D2, D3: CDBU0145-HF; D_0603_1608Metric
F1, F2: 3568; Fuseholder_Blade_Mini_Keystone_3568
FB1: BLM31KN121SH1L; C_1206_3216Metric
J1: TB002-500-06BE; TerminalBlock_Phoenix_MKDS-1,5-6_1x06_P5.00mm_Horizontal
J2: Conn_01x04_Pin; PinHeader_1x04_P2.54mm_Vertical
L1: 1uH; WE-LHMI-5030; MPN 74437336010
L2: 4.7uH; WE-XHMI-6060; MPN 74439346047
R1, R8: 22R; R_0402_1005Metric
R2, R10: 100k; R_0402_1005Metric
R3: 4.99k; R_0402_1005Metric
R4: 33.0k; R_0402_1005Metric
R5: 0; R_0402_1005Metric
R6: 24.0k; R_0402_1005Metric
R7: 15k; R_0402_1005Metric
R9: 10k; R_0402_1005Metric
TP1, TP2: TestPoint_Small; TestPoint_THTPad_D1.0mm_Drill0.5mm
U1: LM62460QRPHRQ1; VQFN-HR-16
U2: TPS7B8133DRVR; DFN-6-1EP_2x2mm_P0.65mm_EP1x1.6mm
U3: NCP730BMT330TBG; DFN-6-1EP_2x2mm_P0.65mm_EP1x1.6mm; not fitted
U4: SN74LVC2G74DCURG4; VSSOP-8_2.4x2.1mm_P0.5mm

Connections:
+3.3V: J2.3; also elsewhere on the board
+3.3VA: C19.2, C20.2, R9.1, U2.6 (VOUT), U3.1 (VOUT), U4.6 (~CLR), U4.8 (VCC); also elsewhere on the board
+5V: C12.1, C13.1, C14.1, C15.1, D2.2 (A), J2.4, L2.2, R2.1, R3.1, U1.5 (BIAS); also elsewhere on the board
+BATT: D1.1 (K), F1.1, FB1.2
/Power/FB: C16.2, R2.2, R6.1, U1.7 (FB)
/Power/SW: C11.1, L2.1, U1.16 (SW)
/Power/VIN: C3.1, C4.1, C5.1, C6.1, C7.1, C8.1, C9.1, C10.1, L1.2, U1.2 (VIN2), U1.14 (VIN1)
/Power/V_LIN: C1.1, C2.1, D2.1 (K), FB1.1, L1.1, R8.2
EN_POWER: TP2.1, U1.13 (EN), U4.5 (Q)
GND: C1.2, C2.2, C3.2, C4.2, C5.2, C6.2, C7.2, C8.2, C9.2, C10.2, C12.2, C13.2, C14.2, C15.2, C17.2, C18.1, C19.1, C20.1, C21.1, D1.2 (A), J1.5, J2.1, R4.2, R5.2, R6.2, R7.1, R10.2, U1.1 (PGND2), U1.8 (AGND), U1.15 (PGND1), U2.3 (GND), U2.4 (GND), U2.7 (GND), U3.3 (GND), U3.7 (GND), U4.4 (GND); also elsewhere on the board
unnamed: C16.1, R3.2
unnamed: F1.2, F2.2, J1.6
unnamed: C11.2, R1.1, U1.4 (CBOOT)
unnamed: R1.2, U1.3 (RBOOT)
unnamed: R4.1, U1.9 (RT)
unnamed: R7.2, U1.11 (SPSP)
unnamed: R5.1, U1.12 (SYNC/MODE)
unnamed: C17.1, U1.6 (VCC)
unnamed: TP1.1, U1.10 (~RESET)
unnamed: C18.2, R8.1, U2.1 (VIN), U2.2 (EN), U3.6 (VIN)
unnamed: U4.2 (D), U4.3 (~Q)
OneWire: J2.2; also elsewhere on the board
P1_OUT: J1.1; also elsewhere on the board
P2_OUT: J1.2; also elsewhere on the board
P3_OUT: J1.3; also elsewhere on the board
P4_OUT: J1.4; also elsewhere on the board
POWER_OFF: R10.1, U4.1 (C); also elsewhere on the board
POWER_ON: C21.2, D3.1 (K), R9.2, U4.7 (~PRE); also elsewhere on the board
POWER_ON_RPI: D3.2 (A); also elsewhere on the board
V_FUSED: F2.1; also elsewhere on the board

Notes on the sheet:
Increase for better EMI performance
Only powering flip-flop, RTC and J5.
Spread Spectrum: On - typ. 20k Ohm Off - 0 Ohm
Supplied by 3.3VA. Needs to be active even U1 is off.
Output Capacitors
Power and 1-Wire connector
Input Filter
min. 10V
EMI Filter
Power from RasPi when VBatt is absent.
Mode: GND means Auto mode
Set switching frequency 200kHz - 2200kHz O Ohm -> 2200kHz 6.81kOhm -> 2200kHz 32.2kOhm -> 500kHz 33.0kOhm -> 488kHz 40.2kOhm -> 400kHz
Cap holds /Preset low when battery power is coming up, leading to a active Q.
R holds clock signal low in case noone is driving it.
24.9k -> 5.0V 24.0k -> 5.17V

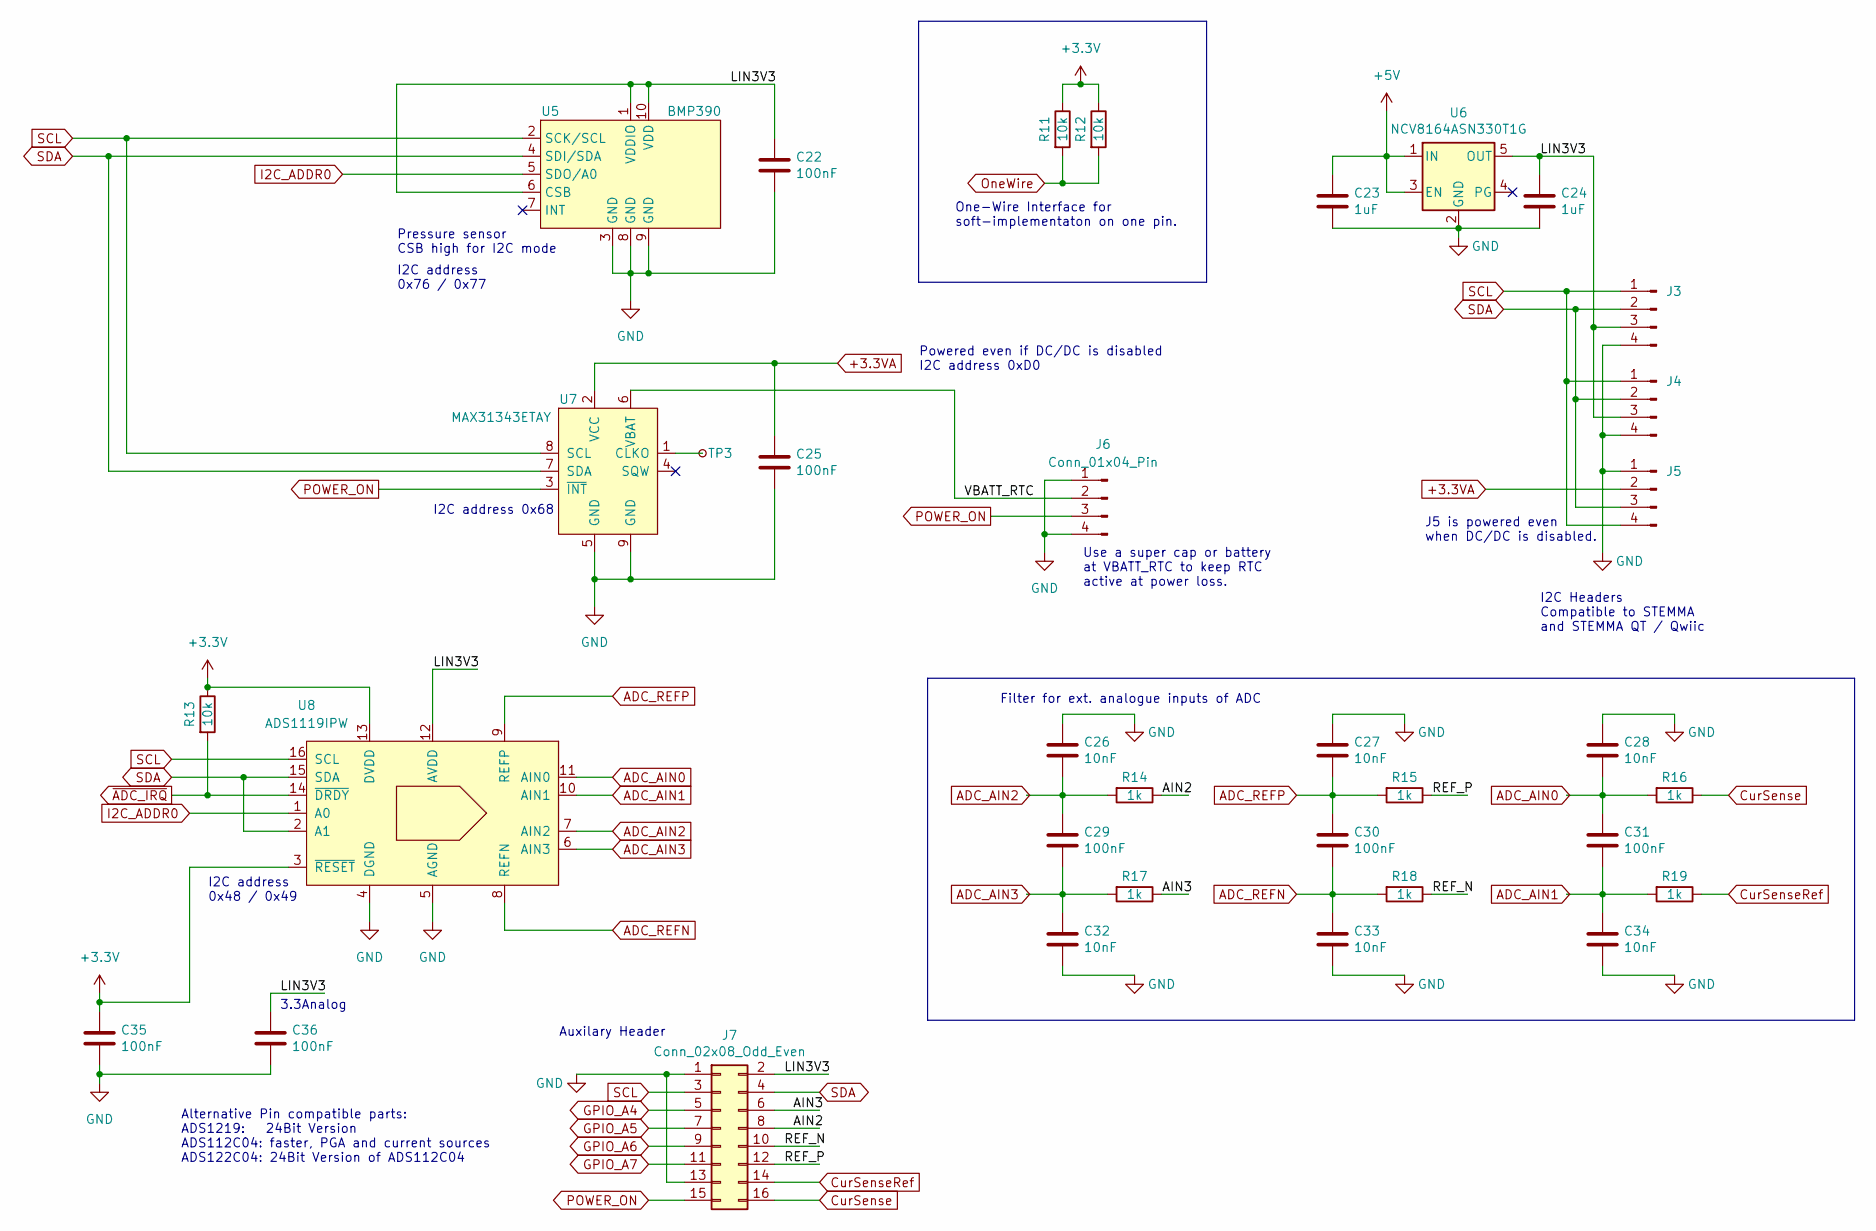
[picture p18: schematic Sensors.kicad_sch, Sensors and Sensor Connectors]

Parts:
C22, C25, C29, C30, C31, C35, C36: 100nF; C_0402_1005Metric
C23, C24: 1uF; C_0402_1005Metric
C26, C27, C28, C32, C33, C34: 10nF; C_0402_1005Metric
J3, J4: B4B-PH-K-S; JST_PH_B4B-PH-K_1x04_P2.00mm_Vertical
J5: SM04B-SRSS-TB; JST_SH_SM04B-SRSS-TB_1x04-1MP_P1.00mm_Horizontal
J6: Conn_01x04_Pin; PinHeader_1x04_P2.54mm_Vertical
J7: Conn_02x08_Odd_Even; PinHeader_2x08_P1.27mm_Vertical
R11, R12, R13: 10k; R_0402_1005Metric
R14, R15, R16, R17, R18, R19: 1k; R_0402_1005Metric
TP3: TestPoint_Small; TestPoint_THTPad_D1.0mm_Drill0.5mm
U5: BMP390; Bosch_LGA-10_2x2mm_P0.5mm
U6: NCV8164ASN330T1G; TSOP-5_1.65x3.05mm_P0.95mm
U7: MAX31343ETAY; SW-TDFN-8-1EP_3x4mm_P0.65mm_EP2.7x2.3mm
U8: ADS1119IPW; TSSOP-16_4.4x5mm_P0.65mm

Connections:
+3.3V: C35.1, R11.1, R12.1, R13.1, U8.3 (~RESET), U8.13 (DVDD); also elsewhere on the board
+3.3VA: C25.1, J5.2, U7.2 (VCC); also elsewhere on the board
+5V: C23.1, U6.1 (IN), U6.3 (EN); also elsewhere on the board
/Sensors/AIN2: J7.8, R14.1
/Sensors/AIN3: J7.6, R17.1
/Sensors/LIN3V3: C22.1, C24.1, C36.1, J3.3, J4.3, J7.2, U5.1 (VDDIO), U5.6 (CSB), U5.10 (VDD), U6.5 (OUT), U8.12 (AVDD)
/Sensors/REF_N: J7.10, R18.1
/Sensors/REF_P: J7.12, R15.1
/Sensors/VBATT_RTC: J6.2, U7.6 (VBAT)
ADC_AIN0: C28.2, C31.1, R16.2, U8.11 (AIN0)
ADC_AIN1: C31.2, C34.1, R19.2, U8.10 (AIN1)
ADC_AIN2: C26.2, C29.1, R14.2, U8.7 (AIN2)
ADC_AIN3: C29.2, C32.1, R17.2, U8.6 (AIN3)
ADC_REFN: C30.2, C33.1, R18.2, U8.8 (REFN)
ADC_REFP: C27.2, C30.1, R15.2, U8.9 (REFP)
CurSense: J7.16, R16.1; also elsewhere on the board
CurSenseRef: J7.14, R19.1; also elsewhere on the board
GND: C22.2, C23.2, C24.2, C25.2, C26.1, C27.1, C28.1, C32.2, C33.2, C34.2, C35.2, C36.2, J3.4, J4.4, J5.1, J6.1, J6.4, J7.1, J7.13, U5.3 (GND), U5.8 (GND), U5.9 (GND), U6.2 (GND), U7.5 (GND), U7.9 (GND), U8.4 (DGND), U8.5 (AGND); also elsewhere on the board
GPIO_A4: J7.5; also elsewhere on the board
GPIO_A5: J7.7; also elsewhere on the board
GPIO_A6: J7.9; also elsewhere on the board
GPIO_A7: J7.11; also elsewhere on the board
I2C_ADDR0: U5.5 (SDO/A0), U8.1 (A0); also elsewhere on the board
unnamed: TP3.1, U7.1 (CLKO)
OneWire: R11.2, R12.2; also elsewhere on the board
POWER_ON: J6.3, J7.15, U7.3 (~INT); also elsewhere on the board
SCL: J3.1, J4.1, J5.4, J7.3, U5.2 (SCK/SCL), U7.8 (SCL), U8.16 (SCL); also elsewhere on the board
SDA: J3.2, J4.2, J5.3, J7.4, U5.4 (SDI/SDA), U7.7 (SDA), U8.2 (A1), U8.15 (SDA); also elsewhere on the board
~ADC_IRQ: R13.2, U8.14 (~DRDY); also elsewhere on the board

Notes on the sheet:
I2C address 0x76 / 0x77
J5 is powered even when DC/DC is disabled.
I2C address 0x48 / 0x49
3.3Analog
I2C Headers Compatible to STEMMA and STEMMA QT / Qwiic
Pressure sensor CSB high for I2C mode
Use a super cap or battery at VBATT_RTC to keep RTC active at power loss.
One-Wire Interface for soft-implementaton on one pin.
Auxilary Header
Filter for ext. analogue inputs of ADC
I2C address 0x68
Powered even if DC/DC is disabled I2C address 0xD0
Alternative Pin compatible parts: ADS1219: 24Bit Version ADS112C04: faster, PGA and current sources ADS122C04: 24Bit Version of ADS112C04

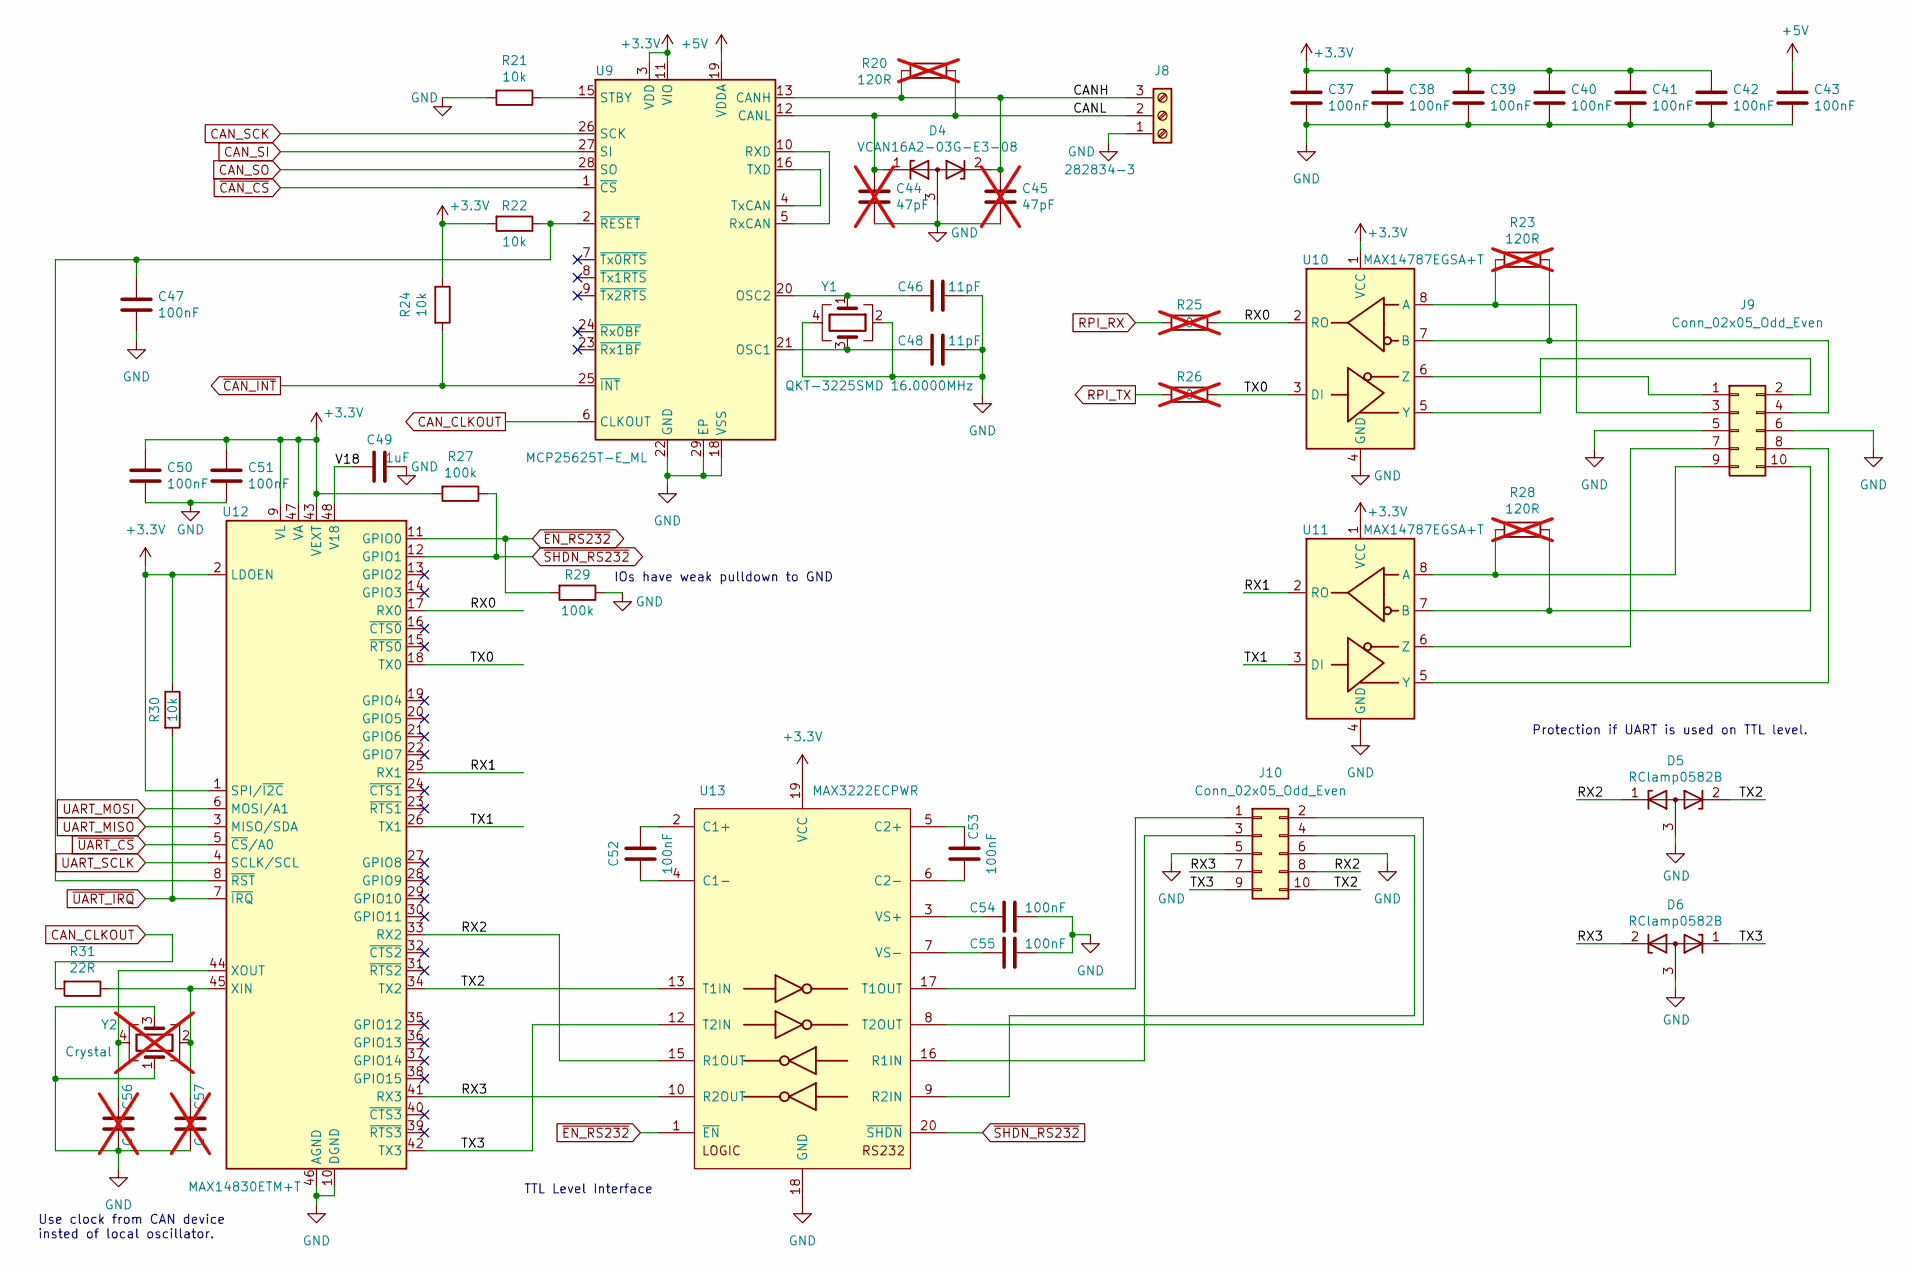
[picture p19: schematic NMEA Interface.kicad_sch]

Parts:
C37, C38, C39, C40, C41, C42, C43, C47, C50, C51, C52, C53, C54, C55: 100nF; C_0402_1005Metric
C44, C45: 47pF; C_0402_1005Metric; not fitted
C46, C48: 11pF; C_0402_1005Metric
C49: 1uF; C_0402_1005Metric
C56, C57: C; C_0402_1005Metric; not fitted
D4: VCAN16A2-03G-E3-08; SOT-323_SC-70
D5, D6: RClamp0582B; SOT-523
J8: 282834-3; TerminalBlock_TE_282834-3_1x03_P2.54mm_Horizontal
J9: Conn_02x05_Odd_Even; PinHeader_2x05_P2.54mm_Vertical
J10: Conn_02x05_Odd_Even; PinHeader_2x05_P1.27mm_Vertical
R20: 120R; R_0603_1608Metric; not fitted
R21, R22, R24, R30: 10k; R_0402_1005Metric
R23, R28: 120R; R_1206_3216Metric; not fitted
R25, R26: 0; R_0402_1005Metric; not fitted
R27, R29: 100k; R_0402_1005Metric
R31: 22R; R_0402_1005Metric
U9: MCP25625T-E_ML; QFN-28-1EP_6x6mm_P0.65mm_EP4.25x4.25mm_ThermalVias
U10, U11: MAX14787EGSA+T; SOIC-8_3.9x4.9mm_P1.27mm
U12: MAX14830ETM+T; TQFN-48-1EP_7x7mm_P0.5mm_EP5.1x5.1mm
U13: MAX3222ECPWR; TSSOP-20_4.4x6.5mm_P0.65mm
Y1: QKT-3225SMD 16.0000MHz; Crystal_SMD_3225-4Pin_3.2x2.5mm
Y2: Crystal; Crystal_SMD_3225-4Pin_3.2x2.5mm; not fitted

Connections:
+3.3V: C37.1, C38.1, C39.1, C40.1, C41.1, C42.1, C50.1, C51.1, R22.2, R24.1, R27.2, R30.1, U9.3 (VDD), U9.11 (VIO), U10.1 (VCC), U11.1 (VCC), U12.1 (SPI/~I2C), U12.2 (LDOEN), U12.9 (VL), U12.43 (VEXT), U12.47 (VA), U13.19 (VCC); also elsewhere on the board
+5V: C43.1, U9.19 (VDDA); also elsewhere on the board
/NMEA Interface/CANH: C45.1, D4.2 (K), J8.3, R20.2, U9.13 (CANH)
/NMEA Interface/CANL: C44.1, D4.1 (K), J8.2, R20.1, U9.12 (CANL)
/NMEA Interface/RX0: R25.1, U10.2 (RO), U12.17 (RX0)
/NMEA Interface/RX1: U11.2 (RO), U12.25 (RX1)
/NMEA Interface/RX2: D5.1 (K), J10.8, U12.33 (RX2), U13.15 (R1OUT)
/NMEA Interface/RX3: D6.2 (K), J10.7, U12.41 (RX3), U13.10 (R2OUT)
/NMEA Interface/TX0: R26.1, U10.3 (DI), U12.18 (TX0)
/NMEA Interface/TX1: U11.3 (DI), U12.26 (TX1)
/NMEA Interface/TX2: D5.2 (K), J10.10, U12.34 (TX2), U13.13 (T1IN)
/NMEA Interface/TX3: D6.1 (K), J10.9, U12.42 (TX3), U13.12 (T2IN)
/NMEA Interface/V18: C49.2, U12.48 (V18)
CAN_CLKOUT: R31.2, U9.6 (CLKOUT)
CAN_SCK: U9.26 (SCK); also elsewhere on the board
CAN_SI: U9.27 (SI); also elsewhere on the board
CAN_SO: U9.28 (SO); also elsewhere on the board
GND: C37.2, C38.2, C39.2, C40.2, C41.2, C42.2, C43.2, C44.2, C45.2, C46.1, C47.2, C48.1, C49.1, C50.2, C51.2, C54.1, C55.1, C56.1, C57.1, D4.3 (A), D5.3 (A), D6.3 (A), J8.1, J9.5, J9.6, J10.5, J10.6, R21.2, R29.1, U9.18 (VSS), U9.22 (GND), U9.29 (EP), U10.4 (GND), U11.4 (GND), U12.10 (DGND), U12.46 (AGND), U12.49 (AGND), U13.18 (GND), Y1.2, Y1.4, Y2.1, Y2.3; also elsewhere on the board
unnamed: J9.1, U10.6 (Z)
unnamed: J9.2, U10.5 (Y)
unnamed: J9.3, R23.2, U10.8 (A)
unnamed: J9.4, R23.1, U10.7 (B)
unnamed: J9.7, U11.6 (Z)
unnamed: J9.8, U11.5 (Y)
unnamed: J9.9, R28.2, U11.8 (A)
unnamed: J9.10, R28.1, U11.7 (B)
unnamed: J10.1, U13.17 (T1OUT)
unnamed: J10.2, U13.8 (T2OUT)
unnamed: J10.3, U13.16 (R1IN)
unnamed: J10.4, U13.9 (R2IN)
unnamed: C48.2, U9.21 (OSC1), Y1.3
unnamed: C46.2, U9.20 (OSC2), Y1.1
unnamed: U9.5 (RxCAN), U9.10 (RXD)
unnamed: R21.1, U9.15 (STBY)
unnamed: U9.4 (TxCAN), U9.16 (TXD)
unnamed: C57.2, R31.1, U12.45 (XIN), Y2.2
unnamed: C56.2, U12.44 (XOUT), Y2.4
unnamed: C47.1, R22.1, U9.2 (~RESET), U12.8 (~RST)
unnamed: C52.2, U13.2 (C1+)
unnamed: C52.1, U13.4 (C1-)
unnamed: C53.2, U13.5 (C2+)
unnamed: C53.1, U13.6 (C2-)
unnamed: C54.2, U13.3 (VS+)
unnamed: C55.2, U13.7 (VS-)
RPI_RX: R25.2; also elsewhere on the board
RPI_TX: R26.2; also elsewhere on the board
UART_MISO: U12.3 (MISO/SDA); also elsewhere on the board
UART_MOSI: U12.6 (MOSI/A1); also elsewhere on the board
UART_SCLK: U12.4 (SCLK/SCL); also elsewhere on the board
~CAN_CS: U9.1 (~CS); also elsewhere on the board
~CAN_INT: R24.2, U9.25 (~INT); also elsewhere on the board
~EN_RS232: R29.2, U12.11 (GPIO0), U13.1 (~EN)
~SHDN_RS232: R27.1, U12.12 (GPIO1), U13.20 (~SHDN)
~UART_CS: U12.5 (~CS/A0); also elsewhere on the board
~UART_IRQ: R30.2, U12.7 (~IRQ); also elsewhere on the board

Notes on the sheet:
TTL Level Interface
Use clock from CAN device insted of local oscillator.
Protection if UART is used on TTL level.
IOs have weak pulldown to GND

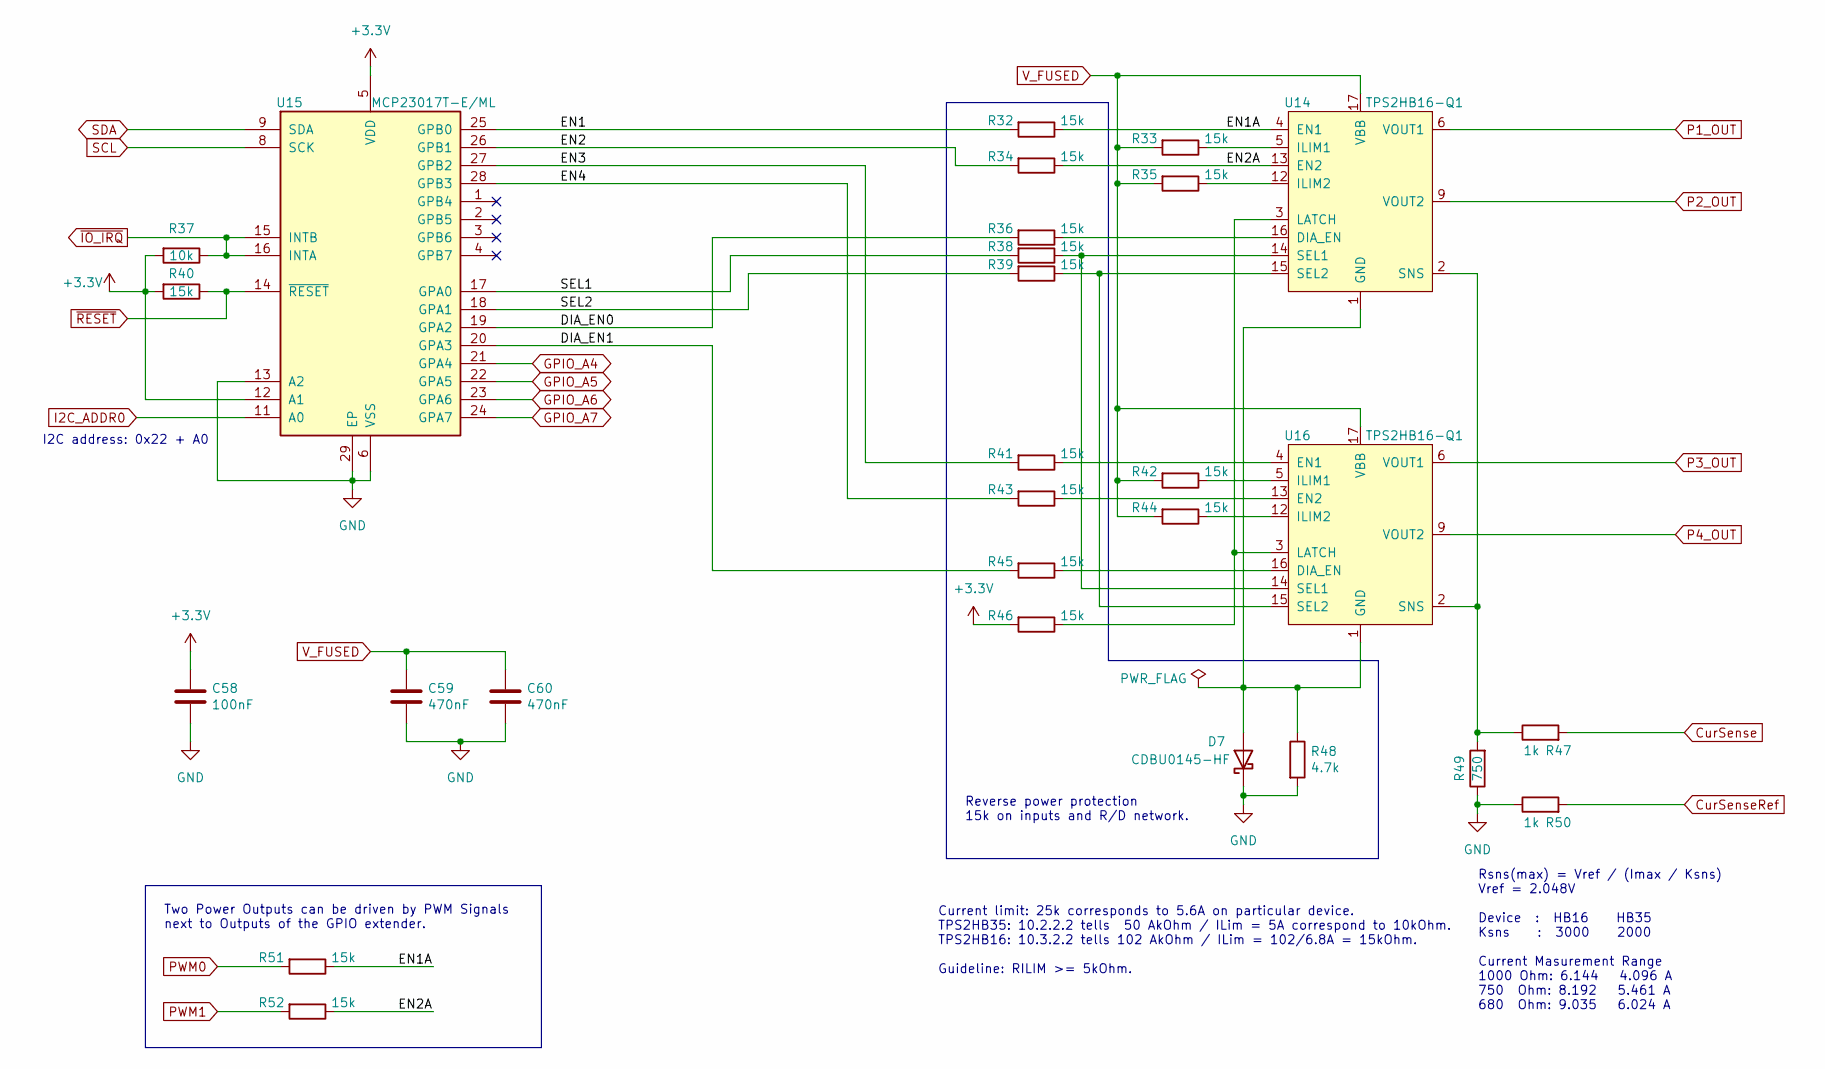
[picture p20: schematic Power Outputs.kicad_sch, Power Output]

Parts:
C58: 100nF; C_0402_1005Metric
C59, C60: 470nF; C_0603_1608Metric; Voltage Rating 50V
D7: CDBU0145-HF; D_0603_1608Metric
R32, R33, R34, R35, R36, R38, R39, R40, R41, R42, R43, R44, R45, R46, R51, R52: 15k; R_0402_1005Metric
R37: 10k; R_0402_1005Metric
R47, R50: 1k; R_0402_1005Metric
R48: 4.7k; R_0402_1005Metric
R49: 750; R_0603_1608Metric
U14, U16: TPS2HB16-Q1; TSSOP-16-1EP_4.4x5mm_P0.65mm
U15: MCP23017T-E/ML; QFN-28-1EP_6x6mm_P0.65mm_EP4.25x4.25mm

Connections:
+3.3V: C58.1, R37.2, R40.2, R46.2, U15.5 (VDD), U15.12 (A1); also elsewhere on the board
/Power Outputs/DIA_EN0: R36.2, U15.19 (GPA2)
/Power Outputs/DIA_EN1: R45.2, U15.20 (GPA3)
/Power Outputs/EN1: R32.2, U15.25 (GPB0)
/Power Outputs/EN1A: R32.1, R51.1, U14.4 (EN1)
/Power Outputs/EN2: R34.2, U15.26 (GPB1)
/Power Outputs/EN2A: R34.1, R52.1, U14.13 (EN2)
/Power Outputs/EN3: R41.2, U15.27 (GPB2)
/Power Outputs/EN4: R43.2, U15.28 (GPB3)
/Power Outputs/SEL1: R38.2, U15.17 (GPA0)
/Power Outputs/SEL2: R39.2, U15.18 (GPA1)
CurSense: R47.2; also elsewhere on the board
CurSenseRef: R50.2; also elsewhere on the board
GND: C58.2, C59.2, C60.2, D7.1 (K), R48.2, R49.1, R50.1, U15.6 (VSS), U15.13 (A2), U15.29 (EP); also elsewhere on the board
GPIO_A4: U15.21 (GPA4); also elsewhere on the board
GPIO_A5: U15.22 (GPA5); also elsewhere on the board
GPIO_A6: U15.23 (GPA6); also elsewhere on the board
GPIO_A7: U15.24 (GPA7); also elsewhere on the board
I2C_ADDR0: U15.11 (A0); also elsewhere on the board
unnamed: D7.2 (A), R48.1, U14.1 (GND), U16.1 (GND)
unnamed: R36.1, U14.16 (DIA_EN)
unnamed: R33.1, U14.5 (ILIM1)
unnamed: R35.1, U14.12 (ILIM2)
unnamed: R46.1, U14.3 (LATCH), U16.3 (LATCH)
unnamed: R38.1, U14.14 (SEL1), U16.14 (SEL1)
unnamed: R39.1, U14.15 (SEL2), U16.15 (SEL2)
unnamed: R47.1, R49.2, U14.2 (SNS), U16.2 (SNS)
unnamed: R45.1, U16.16 (DIA_EN)
unnamed: R41.1, U16.4 (EN1)
unnamed: R43.1, U16.13 (EN2)
unnamed: R42.1, U16.5 (ILIM1)
unnamed: R44.1, U16.12 (ILIM2)
P1_OUT: U14.6 (VOUT1), U14.7 (VOUT1), U14.8 (VOUT1); also elsewhere on the board
P2_OUT: U14.9 (VOUT2), U14.10 (VOUT2), U14.11 (VOUT2); also elsewhere on the board
P3_OUT: U16.6 (VOUT1), U16.7 (VOUT1), U16.8 (VOUT1); also elsewhere on the board
P4_OUT: U16.9 (VOUT2), U16.10 (VOUT2), U16.11 (VOUT2); also elsewhere on the board
PWM0: R51.2; also elsewhere on the board
PWM1: R52.2; also elsewhere on the board
SCL: U15.8 (SCK); also elsewhere on the board
SDA: U15.9 (SDA); also elsewhere on the board
V_FUSED: C59.1, C60.1, R33.2, R35.2, R42.2, R44.2, U14.17 (VBB), U16.17 (VBB); also elsewhere on the board
~IO_IRQ: R37.1, U15.15 (INTB), U15.16 (INTA); also elsewhere on the board
~RESET: R40.1, U15.14 (~RESET)

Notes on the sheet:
Reverse power protection 15k on inputs and R/D network.
Current limit: 25k corresponds to 5.6A on particular device. TPS2HB35: 10.2.2.2 tells 50 AkOhm / ILim = 5A correspond to 10kOhm. TPS2HB16: 10.3.2.2 tells 102 AkOhm / ILim = 102/6.8A = 15kOhm. Guideline: RILIM >= 5kOhm.
Two Power Outputs can be driven by PWM Signals next to Outputs of the GPIO extender.
Rsns(max) = Vref / (Imax / Ksns) Vref = 2.048V Device : HB16 HB35 Ksns : 3000 2000 Current Masurement Range 1000 Ohm: 6.144 4.096 A 750 Ohm: 8.192 5.461 A 680 Ohm: 9.035 6.024 A
I2C address: 0x22 + A0

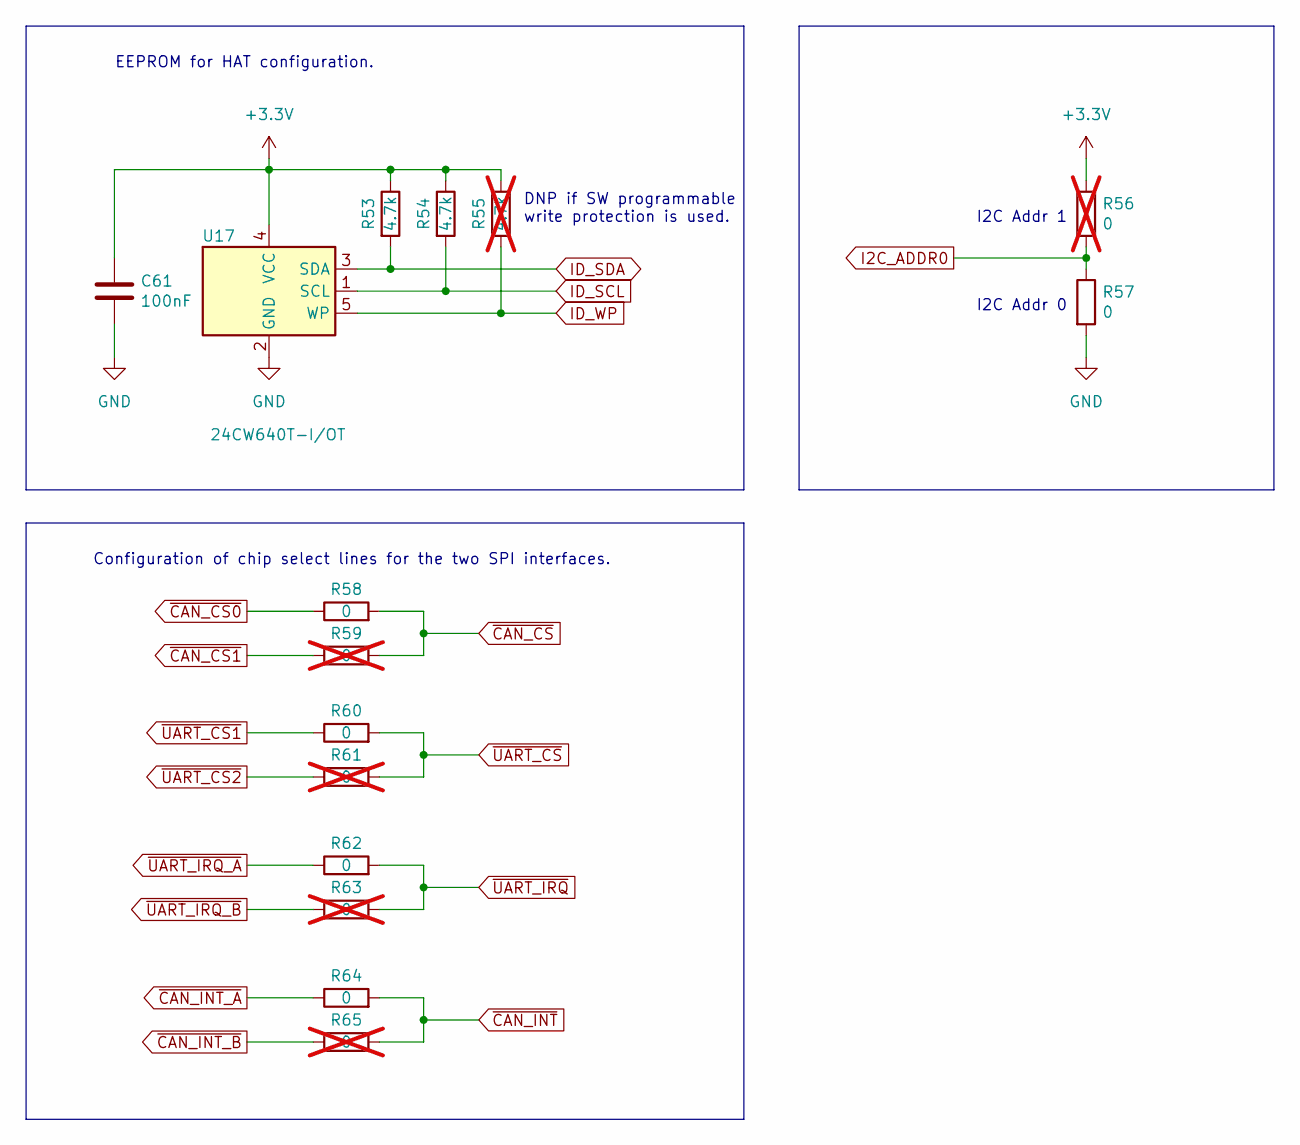
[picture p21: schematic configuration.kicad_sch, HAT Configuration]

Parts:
C61: 100nF; C_0402_1005Metric
R53, R54: 4.7k; R_0402_1005Metric
R55: 4.7k; R_0402_1005Metric; not fitted
R56, R59, R61, R63, R65: 0; R_0402_1005Metric; not fitted
R57, R58, R60, R62, R64: 0; R_0402_1005Metric
U17: 24CW640T-I/OT; SOT-23-5

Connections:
+3.3V: C61.1, R53.1, R54.1, R55.1, R56.1, U17.4 (VCC); also elsewhere on the board
GND: C61.2, R57.2, U17.2 (GND); also elsewhere on the board
I2C_ADDR0: R56.2, R57.1; also elsewhere on the board
ID_SCL: R54.2, U17.1 (SCL); also elsewhere on the board
ID_SDA: R53.2, U17.3 (SDA); also elsewhere on the board
ID_WP: R55.2, U17.5 (WP)
~CAN_CS0: R58.1; also elsewhere on the board
~CAN_CS1: R59.1; also elsewhere on the board
~CAN_CS: R58.2, R59.2; also elsewhere on the board
~CAN_INT_A: R64.1; also elsewhere on the board
~CAN_INT_B: R65.1; also elsewhere on the board
~CAN_INT: R64.2, R65.2; also elsewhere on the board
~UART_CS1: R60.1; also elsewhere on the board
~UART_CS2: R61.1; also elsewhere on the board
~UART_CS: R60.2, R61.2; also elsewhere on the board
~UART_IRQ_A: R62.1; also elsewhere on the board
~UART_IRQ_B: R63.1; also elsewhere on the board
~UART_IRQ: R62.2, R63.2; also elsewhere on the board

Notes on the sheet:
DNP if SW programmable write protection is used.
I2C Addr 1
I2C Addr 0
EEPROM for HAT configuration.
Configuration of chip select lines for the two SPI interfaces.

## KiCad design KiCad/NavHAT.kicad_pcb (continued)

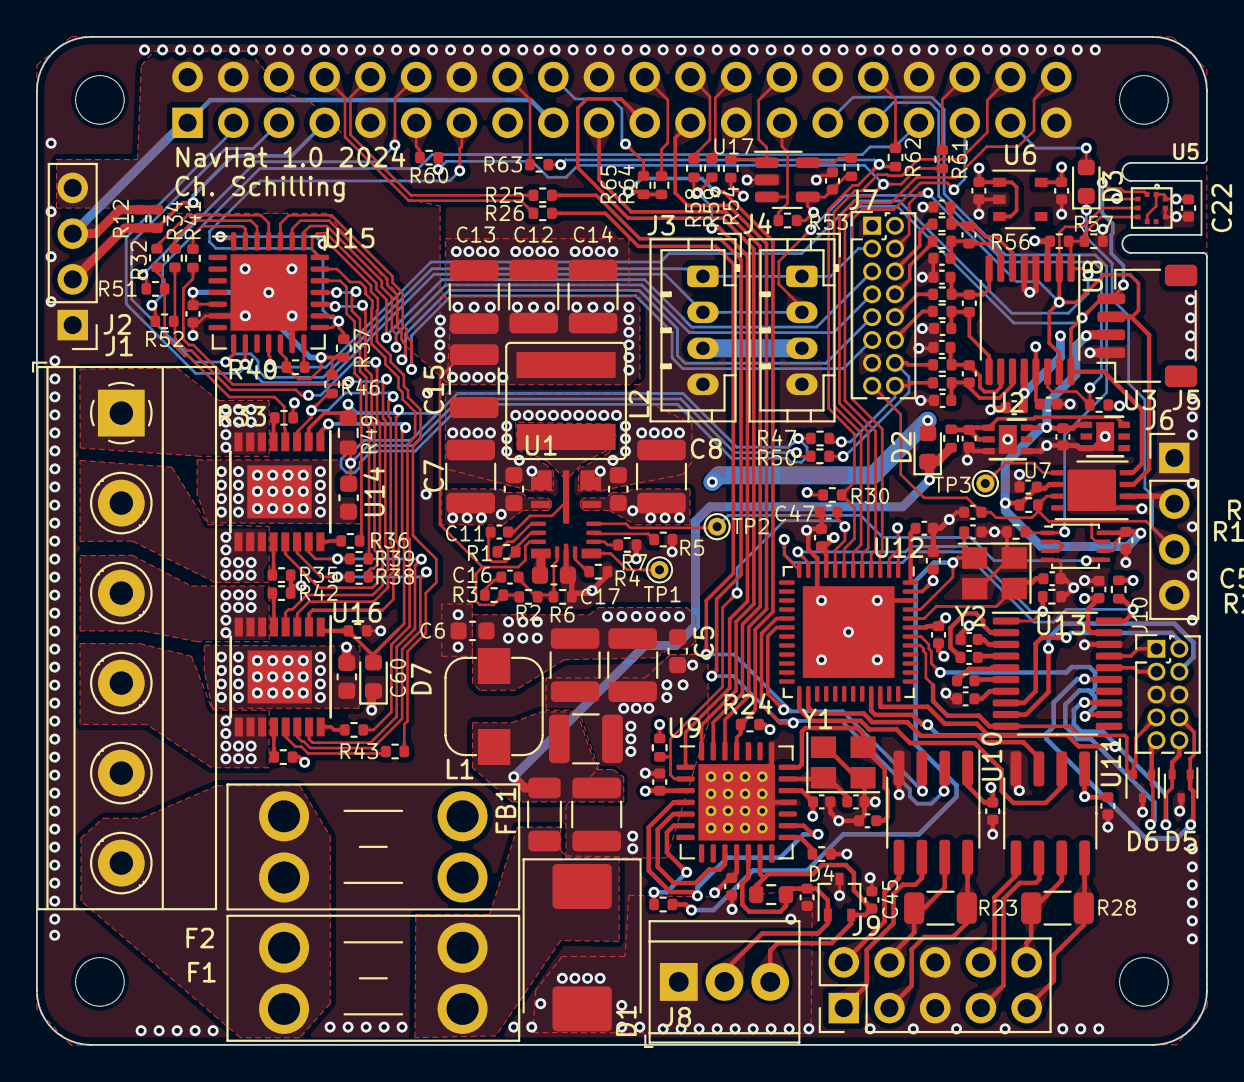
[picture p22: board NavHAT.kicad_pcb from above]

Board: 4 copper layers, 65.0 x 56.0 mm, 175 parts (1 on the bottom side), 143 nets.

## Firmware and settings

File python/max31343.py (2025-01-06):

"""
This module provides a basic interface to the Analog Devices MAX31343 real time clock.
It inherits the I2C read and write access from the i2c_device module.

Christian Schilling     September 2024
"""


import time
import i2c_device

#Registers of MAX31343 datasheet section register map
MAX31343_STATUS         = 0x00
MAX31343_INT_ENABLE     = 0x01
MAX31343_RESET          = 0x02
MAX31343_SECONDS        = 0x06

MAX31343_ALARM2         = 0x13
MAX31343_TRICKLE        = 0x19
MAX31343_TEMPERATURE    = 0x1a

#Flags
INTERRUPT_ALARM1        = 0x01
INTERRUPT_ALARM2        = 0x02
INTERRUPT_TIMER         = 0x04
INTERRUPT_TEMPERATURE   = 0x08
INTERRUPT_POWER_FAIL    = 0x20



def _bcd2bin(a):
    b = ((a & 0xf0) >> 4) *10
    return (b + (a & 0x0f))

def _bin2bcd(a):
    d = a // 10
    r = a % 10
    return ((d << 4) | r)


class MAX31343(i2c_device.i2c_device):
    """
    Provides a python friendly interface to the registers of the RTC MAX31343.

    :param bus: the I2C bus of the connected device. For example 1 or i2c-1
    :type bus: int or str
    :param addr: address of the device. Like 0x20 for a port extender.
    :type addr: int in the range of 0x08 ... 0x77
    :param verbose: setting for printing verbosity information to the console, defaults to False.
    :type verbose: boolean
    """
    def __init__(self, bus_number, i2c_addr, verbose = False):
        super().__init__(bus_number, i2c_addr, verbose)
        self.verbose = verbose
 
    def reset(self):
        """
        Resets the device by setting the corresponding bit in the register via the I2C bus.
        """
        if self.verbose:
            print("Resetting max31343")
        self.write(MAX31343_RESET, [0x01])
        return self
    
    def get_status(self):
        """
        Read status byte from device. Interrupt indicators are cleared afterwards.
        :return: Content of status register.
        :rtype: int, 8bit
        """
        status = self.read(MAX31343_STATUS, 1)[0]
        if self.verbose:
            print("Status max31343: %02x" % (status))
        return status
    
    def set_time(self):
        """
        Sets the time of the RTC. The time is taken from the host using localtime().
        """
        t=time.localtime()
        d=[0,0,0,0,0,0,0]
        d[0] = _bin2bcd(t.tm_sec)
        d[1] = _bin2bcd(t.tm_min)
        d[2] = _bin2bcd(t.tm_hour)
        d[3] = _bin2bcd(t.tm_wday)
        d[4] = _bin2bcd(t.tm_mday)
        d[5] = _bin2bcd(t.tm_mon)
        d[6] = _bin2bcd(t.tm_year % 100)
        if self.verbose:
            print('Time sending to max31343', d)
        self.write(MAX31343_SECONDS, d)
        return self
        
    def get_time(self):
        """
        Reads the time from the device and creats a time string in the ISO format.
        
        :return: Time information from the RTC.
        :rtype: str
        """
        d=self.read(MAX31343_SECONDS, 7)
        isostr = ("%4d-%02d-%02d %02d:%02d %02d" % (_bcd2bin(d[6])+2000, _bcd2bin(d[5]), _bcd2bin(d[4]), _bcd2bin(d[2]), _bcd2bin(d[1]), _bcd2bin(d[0])))
        return isostr
                                                                                                      

    def set_alarm2(self, hour=8, min=0):
        """
        Sets the alarm2 to the hour and minute every day. Each day, the alarm is triggered at the specified time.
        
        :param hour: the hour of the day in the range 0 - 23.
        :type hour: int
        :param min: the min after the set hour in the range 0 - 59.
        :type hour: int
        """
        #disable interrupt alarm2
        ie = self.read(MAX31343_INT_ENABLE, 1)[0] & ~INTERRUPT_ALARM2
        self.write(MAX31343_INT_ENABLE, [ie])
        d=[0,0,0]
        d[0] = _bin2bcd(min)
        d[1] = _bin2bcd(hour)
        d[2] = 0x80 # once every day
        self.write(MAX31343_ALARM2, d)
        #enable interrupt alarm2
        time.sleep(.05)
        ie = self.read(MAX31343_INT_ENABLE, 1)[0] | INTERRUPT_ALARM2
        self.write(MAX31343_INT_ENABLE, [ie])

        
    def set_trickle_charger(self, enable = True, setting = 0x05):
        """
        Sets and configures the trickle charcher of the device. It can be enabled or disabled. The voltage can be lowered by an additional diode (approx. 0.7V). The charging current can flow through a 3, 6 or 11 kOhm resistor.
        
        :param enable: enables or disables the trickle charger, defaults to True.
        :type enalbe: boolean
        :param setting: setting of extra diode and charging resistor, defaults to 0x05 which is extra diode and 3kOhm resistor.
        :type setting: int
        """
        #default setting: extra diode and 3kOhm
        en = 0x00
        if enable: en = 0x50
        self.write(MAX31343_TRICKLE, [(en | setting)])
        return self
        
    def temperature(self):
        """
        Returns the temperature in degrees Celsius as a floating point number.

        :return: Die temperature of the RTC in °C.
        :rtype: float
        """
        reg = self.read(MAX31343_TEMPERATURE, 2)
        self.temp = ((reg[0] <<8) + reg[1]) / 256.0
        #print("Temperature: %02x %02x -> %3.2f °C" % (reg[0], reg[1], self.temp))
        return self.temp
    

    def Diag(self):
        """
        Diag is a demo function to display time and temperature from the device in a terminal.
        """
        
        print("Status: %02x" % self.get_status())
        
        # print static title of the table
        print('MAX31343 real time clock')
        while 1:
            isotime = self.get_time()
            t = self.temperature()
            print("Temperature: %3.2f °C" % (self.temp))
            print("Time       : %s" % (isotime))
            time.sleep(1.0)
            print("\033[A"*3)


if __name__ == '__main__':
    

    SMBUS_NUMBER = 1
    addr = 0x68
    rtc=MAX31343(SMBUS_NUMBER, addr)
    rtc.set_time()
    time.sleep(0.5)
    rtc.set_trickle_charger()
    rtc.set_alarm2(7,56)
    rtc.Diag()

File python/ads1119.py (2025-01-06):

"""
This module provides a basic interface to the Texas Instruments ADS1119 analogue to digital converter.
It inherits the I2C read and write access from the i2c_device module.

Christian Schilling     September 2024
"""

import time
import i2c_device

# register description
ADS119_RESET        = 0x06 
ADS119_START_SYNC   = 0x08
ADS119_POWERDOWN    = 0x02
ADS119_READ_DATA    = 0x10
ADS119_READ_REG     = 0x20
ADS119_READ_BUSY    = 0x24
ADS119_WRITEREG     = 0x40

class ADS1119(i2c_device.i2c_device):
    """
    Provides an interface to the ADC based on the information of the I2C bus and the device address.

    :param bus: the I2C bus of the connected device. For example 1 or i2c-1
    :type bus: int or str
    :param addr: address of the device. Like 0x20 for a port extender
    :type addr: int in the range of 0x08 ... 0x77
    :param verbose: setting for printing verbosity information to the console, defaults to False.
    :type verbose: boolean
    """
    def __init__(self, bus_number, i2c_addr, verbose = False):
        super().__init__(bus_number, i2c_addr, verbose)
        self.verbose = verbose
        
        # configuration options
        self.gain = 1
        self.datarate = 0
        self.mux = 0
        self.ext_vref = 0
        self.continous = 1
        
        # parameters
        self.vref = 2.048
    
    def reset(self):
        """
        Resets the ADC via its reset command over the I2C bus.
        """
        if self.verbose:
            print("Resetting ADS1119")
        self.write(ADS119_RESET, [])

        # configuration reset values
        self.gain = 1
        self.datarate = 0
        self.mux = 0
        self.ext_vref = 0
        self.continous = 0
        return self
        
    def power_down(self):
        """
        shuts down the ADC in sleep mode.
        """
        if self.verbose:
            print("Power down ADS1119")
        self.write(ADS119_POWERDOWN, [])
        return self
    
    def start(self, continous = True):
        """
        Starts the ADC. This can be done for a single measurement of for continous sampling.
        
        :param continous: Flag for continous sampling, defaults to True.
        :type continous: boolean
        """
        self.continous = continous
        if self.verbose:
            print("Starting ADS1119, continous=", self.continous)
        self.write(ADS119_START_SYNC, [])
        return self
        
    def read_data(self):
        """
        Reads the last result from the ADC.
        
        :return: last measured value.
        :rtype: integer, 16Bit two's complement value.
        """
        for k in range(5):
            if self.data_ready():
                blk = self.read(ADS119_READ_DATA, 2)
                value = (blk[0] << 8) + blk[1]
                return value
            else:
                time.sleep(0.01)
        return 0x0000
        
    def write_reg(self, val):
        """
        Writes to the configuration register.
        
        :param val: bit pattern for the configuration register.
        :type val: integer, 8 bits only
        """
        if self.verbose:
            print("Writing configuration ADS1119: %02x" % (val))
        self.write(ADS119_WRITEREG, [val & 0xff])
        return self

    def configure(self):
        """
        Configures the configuration register based on gain, datarate, input multiplexer and voltge reference.
        These parameters are hold in the object.
        """
        # check configuration parameters in correct range
        assert(self.gain == 1 or self.gain == 4)
        assert(self.datarate >= 0 and self.datarate <4)
        assert(self.mux >= 0 and self.mux <8)
        assert(self.ext_vref == 0 or self.ext_vref == 1)
        assert(self.continous == 0 or self.continous == 1)
        
        if self.gain == 1:
            gainval = 0x00
        else:
            gainval = 0x10
        config = self.ext_vref | (self.continous << 1) | (self.datarate << 2) | (gainval) | (self.mux << 5)
        self.write_reg(config)
        
    def read_register(self):
        """
        Reads the configuration register of the ADC.
        
        :return: configuration value.
        :rtype: integer, 8bit only
        """
        blk = self.read(ADS119_READ_REG, 1)
        if self.verbose:
            print("Read configuration of ADS1119 %02x" % (blk[0]))
        return blk[0]

    def data_ready(self):
        """
        Reads the conversion status of the ADC. Information is read from the busy register.
        
        :return: conversion status, reads True if a new reading is available, reads False if conversion data are read.
        :rtype: boolean
        """
        blk = self.read(ADS119_READ_BUSY, 1)
        if self.verbose:
            print("Ready register: %02x" % (blk[0]))
        ready = (blk[0] & 0x80) != 0
        return ready
        
    def read_voltage(self):
        """
        Reads the measured voltage from the ADC in Volts. The result is depending on the measured value, the gain and the voltage reference.
        
        :return: last measured voltage in [v].
        :rtype: float
        """
        bval = self.read_data()
        v = self.gain * (self.vref * bval / 0x7fff)
        return v

if __name__ == '__main__':
    

    SMBUS_NUMBER = 1
    addr = 0x48
    ads=ADS1119(SMBUS_NUMBER, addr)
    ads.reset()
    ads.continous = 1
    ads.configure()
    ads.start()
    time.sleep(0.2)
    
    print("read: ", ads.data_ready(), ads.read_register(), ads.read_data())
    time.sleep(0.1)
    print("read: ", ads.data_ready(), ads.read_register(), ads.read_data())
    time.sleep(0.1)
    print("read: ", ads.data_ready(), ads.read_register(), ads.read_data())
    time.sleep(0.1)

    v = ads.read_voltage()
    

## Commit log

2024-11-10 KiCad Project
    KiCad Files as the project was ordered the first time.
    [CUI_DEVICES_TB002-500-06BE.step, NMEA Interface.kicad_sch, NavHAT.kicad_pcb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]
2024-11-10 PDF of the schematics
2024-11-11 NavHAT.md Power section
2024-11-11 Describing sensor and configuration section.
2024-11-12 Connector descriptions.
2024-11-13 Adding CoC with BOM.
2025-01-06 Basic python files to control I2C devices like RTC, ADC, GPIO controller and high side switches. Files are prepared for sphinx documentation.
2025-02-01 Update NavHAT.md
    Including Drivers chapter.
2025-02-01 Create NavHat-Drivers.md
    Adding drivers chapter for CAN and UART.
